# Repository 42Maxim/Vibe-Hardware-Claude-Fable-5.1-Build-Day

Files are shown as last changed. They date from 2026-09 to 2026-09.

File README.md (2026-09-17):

# Vibe Hardware — describe the intent, get the device

<p align="center">
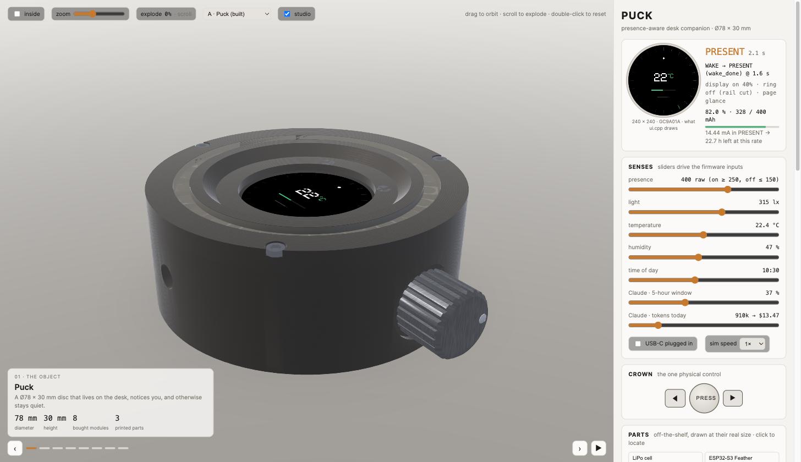
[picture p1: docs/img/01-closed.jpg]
Puck, closed, rendered in the in-browser viewer
  
</p>

**The method has a name, and the first thing it made has a name.** The method is **vibe hardware**.
The object is **Puck**.

## The pitch

Vibe coding gave us "describe the app, get the app." Vibe hardware is the same move on physical things:
**describe what the object should *do*, and get the object** — surveyed, specified, priced, modelled,
firmware'd, and *running on your screen* before a single part is ordered.

You don't hand the model a spec. You hand it an intent: *"something that lives on my desk, notices me, tells me
one thing worth knowing, and otherwise stays quiet."* The model decides the rest — **what** it should be,
**how** it should work, and crucially **what it is made from** — then builds it and lets you hold it,
virtually, from every angle.

## The loop

**Intent → survey → concepts → BOM → geometry → firmware → live emulation.**

The model reads real supplier pages and datasheets *first*, because dimensions are the actual constraints — a
52.3 mm inner diameter decides a form far better than taste does. It proposes several forms, argues each from a
specific part dimension, and commits to one. It locks a shopping list with live links and tonight's prices. It
writes one parametric source of truth that emits both the printable STL **and** the mesh you see. It writes the
firmware. Then it ports that firmware into the browser and *runs it*.

> **`dist/companion.html` is not a 3D model of the device. It is the device.**
> The state machine in that page is the firmware's state machine. The display is drawn pixel-for-pixel by the
> ported `ui.cpp`. The battery drains at the current the datasheets say the real parts draw. Open it with the
> wifi off and it runs: one file, no libraries, no CDN, no assets.

## The hard constraint that makes it real

**Off-the-shelf modules and 3D-printed parts only.** No custom PCB, no tooling, no six-week lead time. Every
component is something a moderately experienced maker can hand-solder, and every plastic part comes off a
desktop printer. That single rule is what turns a beautiful simulation into a thing you can actually own: the
BOM is orderable tonight, the STL is printable tonight, and the gap between the preview and the object on your
desk is a weekend, not a product cycle.

## What it achieves

It collapses the most expensive part of hardware: **the distance between an idea and knowing whether it works.**
Normally you find out the battery can't last a day, or the LED ring doesn't clear the display, after you have
spent the money and two weeks. Here you find out in the browser — the fit check runs exact solid-geometry
booleans, the power table comes from datasheet currents, and the pin budget flags the I²C address collision
before it becomes a returned part.

And it refuses to bluff. The whole project ran under one rule: **nothing is allowed to be merely plausible.**
Every dimension, price, current draw and library version comes from a supplier page or a datasheet that was
actually opened, or it is explicitly marked `unverified`. A made-up number that looks right is worse than a hole.
So the simulation is not a mood board — when it says *22.7 hours left*, that number has a paper trail.

## Puck, the proof

Ø78 × 30 mm. Eight bought modules, three printed parts, ≈ AU$171 / US$95. A presence-aware desk object that
notices when you sit down, shows one thing worth knowing at a glance, glows quietly, and otherwise stays out of
the way: presence, light, temperature and humidity, one knurled crown, a round display, a ring of ambient light,
no tether. 141 detailed sub-parts you can explode with a scroll wheel, down to the bond wires inside the LEDs.
Designed, built and emulated in a single ~2-hour session, from a blank repo.

**Describe the intent. Get a device you can order, print, flash — and play with first.**

| | |
|---|---|
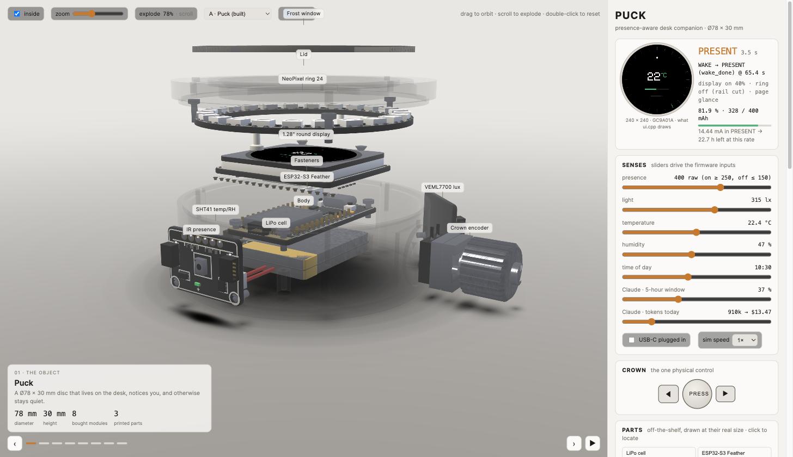
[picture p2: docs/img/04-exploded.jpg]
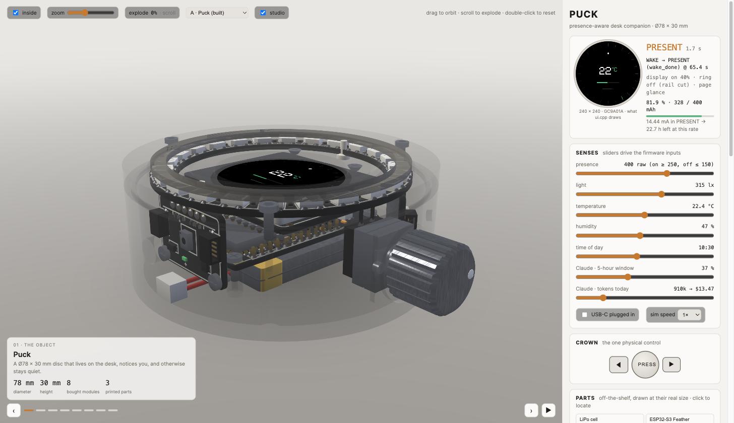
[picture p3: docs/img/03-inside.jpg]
|  |  |
| **Scroll to explode.** Every part leaves along its own assembly axis, fasteners last, labelled as it goes. | **See inside.** The shell goes translucent and the real modules sit where they really sit. |
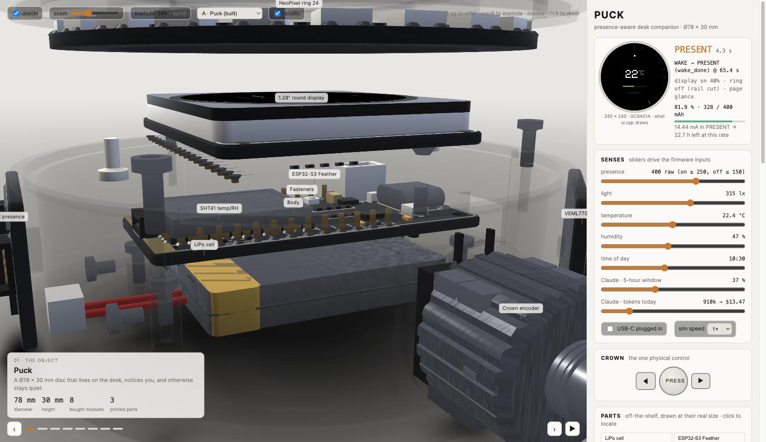
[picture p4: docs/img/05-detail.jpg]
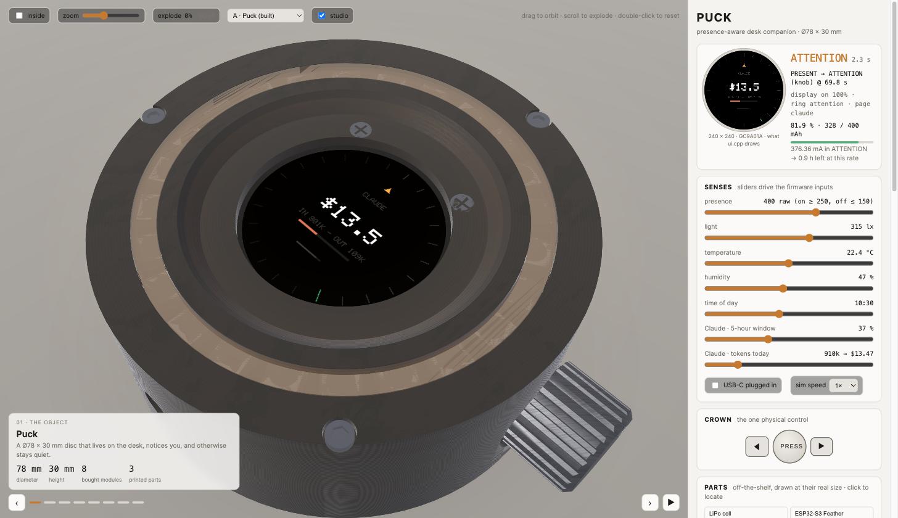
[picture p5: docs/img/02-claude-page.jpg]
|  |  |
| **Real parts, not blocks.** Silkscreen, ENIG pads, solder fillets, castellations, gold headers, Phillips recesses. | **Live display + ambient ring.** Turn the crown to the Claude page; the ring lights, and the power budget reacts. |

---

## What is actually simulated

Most hardware "demos" are an animation of an idea. This one computes:

| Simulated | How |
|---|---|
| **State machine** | `firmware/state_machine.cpp` hand-ported line-for-line to `demo/src/state_machine.js` — same states (`SLEEP · WAKE · PRESENT · NIGHT · ATTENTION · AWAY_PENDING`), same transitions, same guards. The port boundary is marked in a comment banner in both files. |
| **Timing constants** | `build.py` parses every `#define` in `firmware/config.h` and emits them into the page as `FW.*`. Change `T_AWAY_MS` in the firmware and the browser's timeout changes with it. 90 constants cross that boundary. |
| **The display** | `ui.cpp` ported to JS, drawing through a tiny `Adafruit_GFX` shim (including the real 5×7 glcd font) into a 240×240 canvas — the panel's true resolution — which is then textured onto the glass in 3D. `Math.fround` is used where the C code narrows to `float`, so the browser and the MCU round identically. |
| **The LED ring** | `leds.cpp` ported; per-LED colour, brightness cap and animation phase, rendered as 24 emissive segments plus an additive halo through the frosted annulus. |
| **Power** | Per-part, per-mode currents from datasheets in `parts/parts.json` → totals per state → runtime on the chosen cell → the battery readout in the page, drained in real time as you change states. |
| **Fit** | Exact CSG booleans in `geometry/device.py` (not bounding boxes): every component against the internal volume with a 0.5 mm clearance rule. Failures turn red in the 3D view. |
| **Pins** | Every GPIO assigned from `parts.json`, with I²C address collisions flagged (the STHS34PF80 at `0x5A` collides with the DRV2605L haptic — which is why the no-limit tier costs a second board). |

Measured on the page as shipped:

| Mode | Current | Runtime on 400 mAh |
|---|---|---|
| `SLEEP` | 0.12 mA | ~141 days |
| `NIGHT` | 5.04 mA | ~79 h |
| `PRESENT` | 14.44 mA | ~27.7 h |
| `WAKE` / `ATTENTION` (ring lit) | 376.4 mA | ~1 h — event-only by design |

<p align="center">
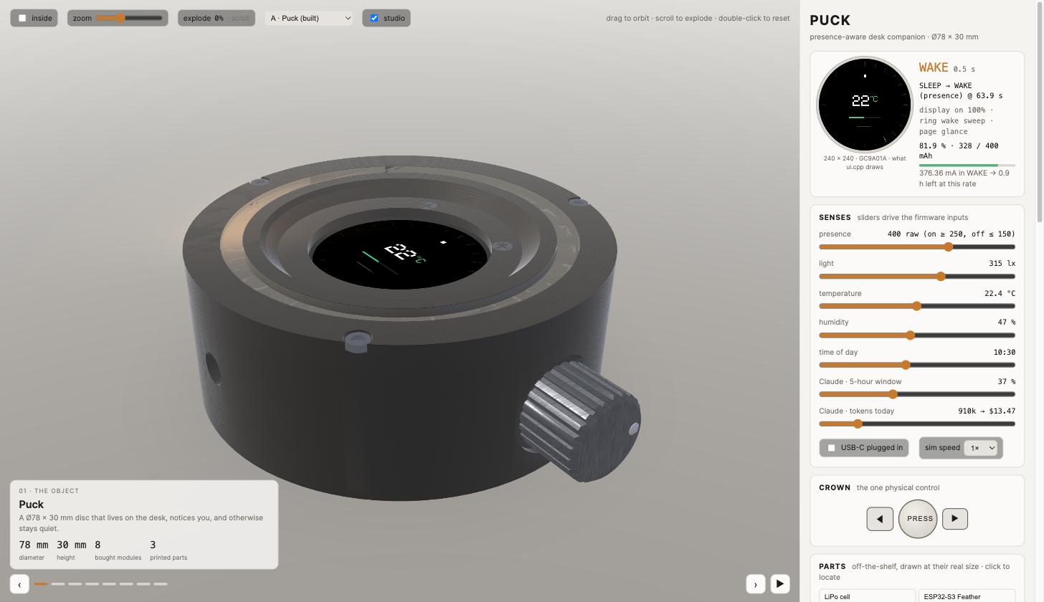
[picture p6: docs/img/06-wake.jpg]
WAKE state: the ring sweeps, the panel reads 376.36 mA and 0.9 h left
  <br>
  <sub><b>SLEEP → WAKE (presence)</b> — the ring sweeps and the readout immediately drops to <b>376.36 mA → 0.9 h left</b>.
  Move the presence slider and the firmware's own transition fires; the cost of that animation is not decorative.</sub>
</p>

The page's own verdict: every continuous mode clears an 8-hour working day; the two ring-lit modes are *burst only*,
which is exactly how the firmware uses them. The ring is the entire power story — 312 mA of the 376 — which is why it
lives on the Feather's **switchable** STEMMA QT rail, is capped at 20 % brightness, and is cut completely in sleep.

---

## How it was designed (the order matters)

1. **Survey the parts first** → [`docs/01-survey.md`](docs/01-survey.md). Real supplier pages and datasheets: board
   footprints, LED ring diameters, battery thicknesses, sensor FoV cones, encoder shaft depths. Dimensions are the
   design constraints, so they come before any drawing.
2. **Four concepts, then commit** → [`docs/02-concepts.md`](docs/02-concepts.md) + a to-scale
   [preview canvas](docs/02-concepts-canvas.html). **A · Puck** ("a hockey puck that knows you're there"),
   **B · Tile** (the lean one), **C · Dial** (the knob *is* the object), **D · Wedge**. Each is argued from a specific
   part dimension, not from taste. Puck won on one number: *the 24-LED ring's 52.3 mm inner diameter is the only ring
   that clears the display module* — the 16-ring's 31.7 mm ID doesn't even clear the 32.5 mm active area. That single
   dimension fixes the cavity, the wall and the whole form. All four still render in the demo's concept switcher.
3. **Lock the BOM** → [`docs/03-bom.md`](docs/03-bom.md). Three tiers, priced in AUD / USD / cheapest-global, every
   line with a live link and one sentence on why that part beat the obvious alternative. Balanced ≈ **AU$171 / US$95**
   (parts 1–8 verified at AU$157.17 / US$88.44); lean ≈ US$50; no-limit ≈ US$130.
4. **One parametric source of truth** → [`geometry/device.py`](geometry/device.py). Python + `manifold3d`. The same
   script emits the printable `build/enclosure*.stl` **and** `build/geometry.json` for the demo, so the thing on
   screen cannot drift from the thing you'd print. It also runs the fit check and prints the verdict.
5. **Firmware** → [`firmware/`](firmware/). Arduino / ESP32-S3, commented, with library versions verified against
   `releases/latest` ([`LIBRARIES.md`](firmware/LIBRARIES.md)) and a host-side test for the state machine.
6. **The demo** → [`demo/src/`](demo/src/) → `python3 build.py` → `dist/companion.html`.

---

## The parts

All off-the-shelf breakouts a moderately experienced maker can hand-solder. No custom PCB, no long leads.

| Module | Why this one |
|---|---|
| Adafruit **ESP32-S3 Feather** (ADA5477) | The only surveyed board with charger + fuel gauge + a *switchable* QT rail — that switch is what cuts the ring's dark current in sleep |
| Adafruit **1.28" round GC9A01A** (ADA6178) | Round glass with two real M2 mounting holes 22.8 mm apart |
| **NeoPixel Ring 24** (ADA1586) | Ø52.3 mm ID — the one ring that clears the display module |
| **STHS34PF80** IR presence (ADA6426) | Lens-free, 80° cone, 10 µA, wakes the MCU on its INT pin |
| **SHT41** (ADA5776) · **VEML7700** (ADA4162) | ±0.2 °C / ±1.8 %RH; 0.0042 lx resolution so a dark room still reads |
| **Bourns PEC11R-4220F-S0024** | 20 mm D-shaft — its 7 mm thread is what lets the crown pass a 3 mm wall with washer and nut |
| 400 / 500 mAh LiPo | The bay is cut 40 × 30 × 6.5 to take either, because the 500 mAh is retired in AU |

---

## Run it

```bash
open dist/companion.html          # that's it — offline, no dependencies
```

Drag to orbit · **scroll to explode** · zoom slider · *inside* toggle · move any sense slider · turn or press the crown.
The panel on the right shows the live state, the last transition that fired, and the battery draining at the modelled rate.

Rebuild everything from source:

```bash
pip install manifold3d numpy
python3 geometry/device.py     # → build/enclosure*.stl + build/geometry.json, prints the fit table
python3 build.py               # → dist/companion.html (inlines geometry, firmware constants, JS/CSS)

# firmware logic test (host-side, no hardware needed)
c++ -std=c++17 firmware/test_state_machine.cpp firmware/state_machine.cpp -o /tmp/sm && /tmp/sm
```

---

## Repo map

| What | Where |
|---|---|
| Parts survey, with a source for every number | `docs/01-survey.md` |
| Concepts A–D + to-scale preview canvas | `docs/02-concepts.md`, `docs/02-concepts-canvas.html` |
| BOM, three tiers × AU/US/global | `docs/03-bom.md`, data in `parts/parts.json` |
| Aesthetic, mechanical, wiring, assembly, quick start | `docs/04-design.md` |
| Parametric geometry → STL + demo mesh + fit check | `geometry/device.py` → `build/` |
| Firmware + host-side test + verified library versions | `firmware/` |
| 1:1 JS port of state machine / display / LEDs | `demo/src/{state_machine,ui,leds}.js`, `demo/src/PORT_CHECK.md` |
| Hand-written WebGL viewer, tables, app | `demo/src/{gl,tables,app}.js` |
| Claude usage push (the device's 5th page) | `tools/claude_usage_push.py` |

### About the viewer

`demo/src/gl.js` is hand-written WebGL1 — shaders, matrix maths, arcball, picking, glow sprites and all. No three.js,
nothing doing the hard part. It renders 144 parts / 82k triangles at ~0.4 ms of CPU per frame, with GGX material
shading driven by a per-part material name (soldermask, ENIG gold, tinned solder, anodised aluminium, glass, pouch
foil, printed PETG…), crease-angle normal smoothing, procedural micro-detail and contact occlusion.

The 141 detailed sub-part meshes come out of the same parametric source as the STL: the WS2812B packages carry their
three dies and bond wires, the boards carry silkscreen and pads as real relief, the screws have Phillips recesses, and
the encoder's D-flat is 4.5 mm across because that is what the Bourns drawing says.

---

<sub>Built on Build Day, Brisbane, 2026-09-16, with Claude Code. Standing rules for the repo live in `CLAUDE.md`;
the original brief is in `PROMPT.md`.</sub>

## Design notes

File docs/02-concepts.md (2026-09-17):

# 02 · Concepts

Four forms, each arranged from the parts in `01-survey.md` at their real dimensions.
Preview: `docs/02-concepts-canvas.html` (to-scale SVG sections, local file, open in a browser).

---

## A · Puck — "a hockey puck that knows you're there"

**Form.** Ø74 × 24 mm disc, flat top, 1 mm radius edge. Frosted ring inset in the top face, round display dead centre, an IR window on the front chamfer, and a knurled crown on the right side like a watch.

**Inside.** Top layer: Adafruit 1.28" round GC9A01 module (42.4 × 36.2 × 5.4) centred, NeoPixel Ring 24 (OD 65.5 / ID 52.3 / 3.2 thick) concentric around it under a 3 mm frosted PETG ring. Middle layer: ESP32-S3 Feather (52.3 × 22.7 × 7.2) running front-to-back with USB-C through the rear wall; SHT41 and VEML7700 lying flat in the left and right crescents beside it (VEML7700 reads ambient through the frosted ring). STHS34PF80 standing vertical against the front wall, element facing forward through a Ø6 window, its 80° cone covers a seated person at 0.5–1.5 m. Bottom layer: 500 mAh cell (36 × 29 × 4.75) under the Feather. PEC11R encoder (20 mm shaft, 7 mm thread) through the right wall.

**The dimension that makes it work.** The 24-ring's 52.3 mm inner diameter clears the display module's 42.4 × 36.2 outline with 5 mm to spare; the 16-ring's 31.7 mm ID does not even clear the 32.5 mm active area. That single number makes this a 24-LED object, fixes the inner cavity at Ø68, and the wall at 3 mm gives Ø74. The Feather's 52.3 mm length sits on a Ø68 chord only within ±11 mm of centre, which is why it runs through the middle and the sensors go in the crescents.
**Fights back.** Height: 2 + 4.75 + 7.2 + 5.4 + 3 with 0.5 mm gaps is 23.4 mm; nothing can be added vertically. The 24-ring idles at ~24 mA dark, so it needs its own high-side switch.

**Easy:** one focal point, symmetric, printable as two parts (body + lid). **Costs:** the 24-ring is the dearest LED option, the crown needs a good knob. **Tier:** balanced.

---

## B · Tile — "a standing card, the lean one"

**Form.** 32 × 16 × 62 mm standing tile in a shallow base, display landscape at eye level.

**Inside.** Adafruit ESP32-S3 Reverse TFT Feather (22.9 × 50.8, 240×135 display on its back face) standing vertically; the tile is the Feather plus 4.5 mm of wall on each side. 350 mAh cell (36 × 19.6 × 5.2) behind it. STHS34PF80 in the base facing forward. SHT41 in the base. No ring: the only ambient light is the Feather's single on-board NeoPixel glowing through the base — or a 12-ring (36.8 OD) laid flat in a Ø40 base as a floor glow.

**The dimension that makes it work.** The Feather's 22.9 mm width is the whole object's width; nothing else needs to fit beside it. **Fights back.** The 1.14" display is off-centre on the Feather (three buttons take the top 8 mm of the face), so the tile's window is asymmetric, and the 240×135 panel at 16 mm wide reads as a status bar, not a face. The three onboard buttons are the "one control" — tactile, not rotary.

**Easy:** cheapest, no display wiring, one board. **Costs:** the ambient light is an afterthought, the display is small. **Tier:** lean.

---

## C · Dial — "the knob is the object"

**Form.** 80 × 56 × 28 mm wedge, 12° top slope. A Ø30 knob rises 8 mm from the top right, a 16-LED ring glows in the annulus around it, a 1.3" square display sits to the left.

**Inside.** NeoPixel Ring 16 (44.5 OD / 31.7 ID / 6.7 thick) under a frosted annulus, PEC11R at its centre with a Ø28 knob (the 31.7 ID leaves 1.85 mm around a 28 mm knob). Adafruit 1.3" 240×240 ST7789 (35.8 × 35.8) at the left. Feather flat under both, 1200 mAh cell (62 × 34) flat under the Feather. STHS34PF80 on the front face.

**The dimension that makes it work.** The 16-ring's 31.7 mm ID is exactly a knob-sized hole; that ring only makes sense around a control. **Fights back.** The ring's 6.7 mm thickness plus the 12.5 mm encoder body under the knob stacks to 19 mm before the Feather, so the wedge is 28 mm tall and the two focal points (knob halo + display) compete.

**Easy:** great tactile feel, long battery (1200 mAh). **Costs:** two visual centres, largest footprint. **Tier:** no-limit (knob machined, ring + display + haptics).

---

## D · Wedge — "a tiny monitor with a halo on the desk"

**Form.** 76 × 50 × 32 mm, 25° sloped face, landscape display.

**Inside.** Adafruit 1.69" 280×240 (45.8 × 36.8) in the sloped face. NeoPixel Ring 12 (36.8 OD) mounted face-down in the base so the glow lands on the desk as an underglow halo. 1200 mAh cell lying flat under the slope. STHS34PF80 above the display. Encoder on the right end.

**The dimension that makes it work.** The 1.69" panel's 38 × 30 mm active area is the largest surveyed that fits a 50 mm-deep face at 25°. **Fights back.** The underglow depends on the desk finish (nothing on black), and the 62 mm cell forces the 76 mm length.

**Easy:** most legible display. **Costs:** the ambient light is indirect and surface-dependent; the form is a familiar "gadget" shape. **Tier:** balanced.

---

## Recommendation: A · Puck

The puck is the only form where every part sits where its dimension wants it: the 24-ring is concentric with the round display because 52.3 > 42.4, the Feather runs through the middle because 52.3 mm fits a Ø68 chord only there, the cell stacks under it because the disc has exactly one layer to spare, and the presence sensor's 80° cone faces the person through the front wall without a lens. One focal point, quiet when you are not there, a crown you can turn without looking. The tile (B) is cheaper but its light and display are compromises; the dial (C) has two centres; the wedge (D) is a shape you have already seen and its glow depends on the desk.

Committed: Puck. Concept previews in `02-concepts-canvas.html`.

**Post-fit note (geometry/device.py):** the concept sketch said Ø74 × 24. The exact fit check grew it to **Ø78 × 30**: the 24-ring cannot share a plane with the display module (the module's corners sit at r 27.9, inside the ring's 26.15 inner radius), so the ring moved up into the lid and the display sits in a 2.4 mm dish below it (+6 mm height); and the VEML7700 standing at 45° needs a Ø72 cavity to clear both the wall and the display corner by 0.5 mm (+4 mm diameter). The sketch's reasoning stands; the numbers in `build/geometry.json` are the truth.

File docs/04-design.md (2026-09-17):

# 04 · Design — Puck

Concept A, locked. Every dimension below comes from `parts/parts.json`, `docs/01-survey.md`,
`docs/03-bom.md` or the locked mechanical layout. Anything I could not derive from those is
written **unverified** rather than filled in. Coordinates: origin at the centre of the base
underside, z up, **−y front** (user), **+y rear** (USB), **+x right** (crown).

Geometry is the post-fit-check layout (cavity Ø72, outer Ø78). Two open items are marked **C1**
and **C2** in §2.4 — each names the problem and the minimum change that clears it.

---

## 1 · Aesthetic direction

A matte black disc the size of a coaster that sits still and says one thing. The top is two
surfaces: a flat rim and a shallow dish sunk 3 mm into it, with the round glass dead centre and
a frosted band of white light around the outside edge — a halo that is either off or holding one
steady colour. The only thing that moves is the crown on the right: a 16 mm knurled cylinder at
finger height, one click per detent, the kind of control you turn without looking down. Material
feel is matte PETG against frost against glass; no gloss, no chrome, no logo, no seam you can see
from a seated eye line. Personality: it notices you and then leaves you alone. It must never blink,
never breathe, never idle-animate, never show a menu, never ask for anything. If you are not
there, it is black and silent, and that is the state it should be in most of the day.

---

## 2 · Mechanical design

### 2.1 Overall

| Dimension | Value | Source |
|---|---|---|
| Outer diameter | Ø78 | layout |
| Cavity diameter | Ø72 (r 36) | layout |
| Total height (feet excluded) | 30 | layout |
| Wall thickness | 3 | layout |
| Floor thickness | 2 (cavity z 2…25) | layout |
| Lid | z 25…30; lip drops into a 1.4 wide × 1.5 deep rebate in the wall top, 0.3 clearance | layout |
| Lid fixing | 3 × M2 at **75° / 195° / 315°** from +x, CCW from above, bolt circle r 36.5; bosses Ø5 with Ø1.6 pilots; lid has M2 clearance holes with 1.5 deep head recesses | layout |
| Lid top rim | annulus r 25.5…39 at z 30 (outer radius follows the new Ø78 — derived) | derived |
| Lid centre dish | r < 22.5, surface at z 27, 45° transition to the rim, 2 thick | layout |
| Display window | Ø34 through the dish | layout |
| Ring pocket | cut from below, z 24…28.4, r 25.45…33.45 | layout |
| Frosted window | annulus r 28.5…32.5, z 28.4…30 | layout |
| IR window (presence) | Ø6 in the front wall at z 14.8 | layout |
| Light window (lux) | Ø3 through the wall at 45° (right-rear), z 14.8 | layout |
| Breathing holes | 4 × Ø2 through the floor under the SHT41, at ±4 from its centre | layout |
| Crown bushing hole | Ø7.2 at y +4, z 12; Ø18 × 1.5 knob dimple outside → 3.1 panel | layout |
| USB-C slot | 12 × 7 through the rear wall, centred z 12 — sized for the plug overmould (overmould size unverified) | layout |
| Feet | 3 × Ø8 silicone bumpers; **foot radius unverified** — keep them clear of the breathing holes | layout |

### 2.2 z-stack on the centreline

| z (mm) | What | Thickness |
|---|---|---|
| 0…2 | floor | 2 |
| 2…8 | LiPo cell (AU 400 mAh, 6 thick; US 500 mAh is 4.75 → 2…6.75) | 6 |
| 8…9 | air over the cell | 1.0 |
| 9…16.2 | ESP32-S3 Feather on 4 posts | 7.2 |
| 16.2…19.2 | wiring plenum | 3.0 |
| 19.2…24.6 | display module (glass top 2.4 below the dish surface at z 27) | 5.4 |
| 24.6…25.0 | gap to the dish underside — 0.4 standoff bosses | 0.4 |
| 25.0…30.0 | lid: ring 25.2…28.4, frost 28.4…30.0, pocket void 24…28.4 at r 25.45…33.45 | 5.0 |

Sum = 30.0. Ring top and frost underside now meet at 28.4 — the earlier 0.3 mm interference between
them is gone, and the LEDs bear straight on the diffuser, which is what you want optically.

### 2.3 Part-by-part mounting

| Part | Size (mm) | Placed at | How it is held |
|---|---|---|---|
| NeoPixel Ring 24 | OD 65.5 / ID 52.3 / 3.2 | lid pocket, z 25.2…28.4, LEDs up against the frost; 0.7 radial clearance each side (pocket r 25.45…33.45 vs ring r 26.15…32.75), 1.2 of pocket below the ring for leads and solder | 3 hot-glue dabs or 2 × M2 nylon screws into lid bosses (fixing method chosen, not in the layout) |
| Frosted window | r 28.5…32.5, 1.6 thick | lid top, z 28.4…30 | printed separately in natural PETG, bonded into the rebate |
| Display module | 42.4 × 36.2 × 5.4 | centred (0, 0), z 19.2…24.6 | 2 × M2 countersunk through the dish into the module's 2 holes, 22.8 apart, onto 0.4 standoff bosses; **hole positions on the PCB unverified** (parts.json) |
| Feather | 52.3 × 22.7 × 7.2 | centre (0, +1.5), long axis front-to-back (y −24.65…+27.65), PCB bottom z 9.0 | 4 posts Ø4 × 7 (M2 self-tap, Ø1.6 pilot — pilot chosen) at (±8.8, −22.1) and (±8.8, +25.1); pattern 17.6 × 47.2, consistent with a 2.5 edge inset, but the Feather's **hole inset is unverified** in the survey |
| LiPo cell | 38 × 25 × 6 (AU) / 36 × 29 × 4.75 (US) | floor, under the Feather, x ±12.5, y −17.5…+20.5, z 2…8 | 40 × 30 × 6.5 bay per BOM line 7, foam pad + one cable tie |
| STHS34PF80 | 25.5 × 17.6 × 4.7 | vertical on the front wall, y −31.5…−26.8, x ±12.75, z 6…23.6, element facing −y | 2 × M2 into ribs off the front wall; the wall is 4.5 off the board back at the centreline, so the ribs carry it |
| VEML7700 | 25.5 × 17.6 × 4.6 (parts.json, **PCB size unverified**) | **vertical** against the wall at 45° (right-rear): inner face r 28.5, outer r 33.1, 25.5 tangential, z 6…23.6, sensor facing out through the Ø3 window at z 14.8 | 2 × M2 into ribs off a flat pad at 45°; 2.9 of air behind the board at its centre |
| SHT41 | 25.5 × 17.6 × 4.8 | **flat on the floor**, left crescent, centred (−22, −2), 25.5 along y, z 2…6.8 | 2 × M2 posts off the floor, over the 4 breathing holes |
| Encoder PEC11R-4220F-S0024 | body 12.5 × 13.4 × 10.7, M7 × 0.75 bushing, 20 mm shaft, 7 mm thread | flat printed pad on the inside of the right wall, mounting face x 34.4; body x 23.7…34.4, y −2.25…+10.25, z 5.3…18.7 | M7 washer + nut outside in the dimple; panel 3.1 thick leaves 3.9 of thread proud |
| Knob | Ø16 × 12, seated in the Ø18 × 1.5 dimple | on the D-flat | grub screw; **part not selected — unverified** (printed or machined) |

### 2.4 Clearances (computed from the layout)

Cavity wall is r 36, so what matters is a part's worst **corner radius**, not its width.

| Pair | Clearance | Note |
|---|---|---|
| Display corners (r 27.88) ↔ cavity wall r 36 | 8.13 | corners at (±21.2, ±18.1) |
| Display active Ø32.5 ↔ window Ø34 | 0.75 radial | glass 38.1 × 35.6 overlapped by 2.05 (x) / 0.80 (y) of bezel |
| Display glass top 24.6 ↔ dish surface z 27 | 2.4 sunk | the dish shades the glass |
| Display top 24.6 ↔ dish underside 25.0 | 0.4 | standoff bosses; the 2 screws pull the module up to them |
| Display top 24.6 ↔ ring underside 25.2 | 0.6 | the module's half-diagonal 27.88 exceeds the ring's 26.15 ID radius, so display and ring are **not** coplanar — 0.6 is all that separates them |
| Display bottom 19.2 ↔ Feather top 16.2 | 3.0 | wiring plenum |
| Feather rear corners (±11.35, +26.65) ↔ wall | 7.51 | wall at y 34.16 for x ±11.35 |
| Feather front corners ↔ wall | 8.51 | |
| Feather PCB bottom 9.0 ↔ cell top 8.0 | 1.0 | 2.25 on the thinner US cell |
| Cell ↔ front / rear posts | 2.6 each | y −17.5 vs post face −20.1; y +20.5 vs +23.1 |
| Cell edge x −12.5 ↔ SHT41 edge x −13.2 | 0.7 | closest pair on the floor |
| Feather rear edge 27.65 ↔ inner wall face 36.0 | 8.35 | USB-C plug reach — the plug overmould enters through the 12 × 7 slot, **see C1** |
| STHS34PF80 back (y −31.5) ↔ wall at x ±12.75 (y −33.67) | 2.17 | 4.5 at the centreline |
| STHS34PF80 rear face −26.8 ↔ Feather front −25.65 | 1.15 | |
| STHS34PF80 rear face −26.8 ↔ front posts (face −25.1) | 1.70 | |
| STHS34PF80 top 23.6 ↔ lid underside 25.0 / ring 25.2 | 1.40 / 1.60 | its top corners sit at r 29.7…34.0, i.e. under the pocket mouth |
| VEML7700 inner face (r 28.5 at 45°) ↔ nearest display corner | **0.71** | display corner projects to 27.79 on the 45° ray |
| VEML7700 outer corners (r 35.47) ↔ cavity wall r 36 | 0.53 | tightest wall clearance in the device |
| VEML7700 ↔ encoder body | 4.33 tangential | encoder's nearest corner sits at t −17.08 on the 45° frame; board spans ±12.75 |
| VEML7700 outer corner ↔ 75° lid boss (Ø5 at r 36.5) | 3.20 | 195° and 315° bosses clear everything by ≥ 4.4 |
| SHT41 corners (r 34.15 / 32.79) ↔ wall | 1.85 / 3.21 | |
| SHT41 top 6.8 ↔ Feather bottom 9.0 | 2.20 | no plan overlap anyway |
| Encoder body top 18.7 ↔ display bottom 19.2 | **0.50** | tightest vertical pair |
| Encoder body ↔ display in plan | 2.50 lateral | body starts at x 23.7, display ends at 21.2 |
| Encoder body rear x 23.7 ↔ Feather x 11.35 | 12.35 | |
| Encoder body bottom 5.3 ↔ floor top 2.0 | 3.30 | |
| Ring pocket outer r 33.45 ↔ lid boss inner edge r 34.0 | 0.55 | the bosses only just miss the pocket |
| Ring OD r 32.75 ↔ lid outer skin r 39 | 6.25 of lid material | |

**Fit verdict: pass on a 0.5 mm rule.** The three closest pairs are encoder-to-display 0.50 (z),
VEML-to-display-corner 0.71, and SHT41-to-cell 0.70 — which matches the geometry fit check.
Two things still need a decision:

- **C1 — USB-C reach.** The Feather sits 1.5 mm rearward (rear edge 8.35 mm from the inner wall
  face; any further and its rear corner breaks the 0.5 mm rule against the 45° VEML board). The slot is
  12 × 7 through the full 3 mm wall so the plug's overmould passes into the cavity and seats on the port;
  nothing lies in that path (posts at x ±8.8, slot ±6). A USB-C plug shell is nominally 6.5 mm long and overmoulds are
  **unverified** (I did not open a connector spec), so **test-fit your actual cable in a printed
  coupon before committing the body print**; if it still does not seat, fit a short USB-C extension pigtail inside.
- **C2 — encoder shaft length.** With the body face at x 34.4, the 7 mm thread ends at x 41.4 —
  3.9 proud of the dimple floor (37.5) for washer and nut, which is right. But the 20 mm shaft ends
  at x 54.4, about 3.9 mm past the outer face of a 12 mm knob, so **cut the shaft to 16 mm** and
  deburr. The knob also needs a counterbore over the nut: depth ≈ 4, diameter **unverified**
  (M7 × 0.75 nut across-flats not read from a datasheet).

### 2.5 Tolerances, print orientation, settings

| Item | Value |
|---|---|
| Pockets (ring, frost rebate, sensor bays, cell bay) | +0.2 on each dimension |
| Lid rebate | 1.4 × 1.5 with +0.3 clearance on the lip (as specified) |
| Bushing hole | Ø7.2 for an M7 × 0.75 bushing |
| M2 self-tap pilots | Ø1.6 (posts and lid bosses) |
| M2 clearance holes | Ø2.4, 1.5 deep head recesses in the lid |
| Body print | floor down, no supports; the USB slot, the Ø6 and Ø3 windows bridge; the Ø7.2 bushing hole prints horizontal and is reamed |
| Lid print | rim face down on the plate, dish and pockets up; no supports |
| Frost print | flat, natural/clear PETG, **0.4 mm layers** (the layer lines are the diffuser) |
| Layers / nozzle | 0.2 mm / 0.4 mm for body and lid |
| Walls / infill | 3 perimeters, 30 % gyroid (chosen) |
| Material / colour | body matte black or warm grey PETG; **all interior surfaces white PETG** for light bounce; frost natural PETG |
| PETG profile | 240 °C / 80 °C bed, 40 mm/s outer wall (chosen defaults) |

### 2.6 Light path and sensing path

- **Halo.** 24 LEDs on a 29.45 pitch radius fire up into a 1.6 mm frost band at r 28.5…32.5, in
  contact with the diffuser — so the band reads as one continuous ring, not 24 dots. White interior
  walls pick up the spill through the open pocket mouth and keep the dish evenly lit from below.
- **Display.** Ø34 window over a Ø32.5 active area: 0.75 mm of bezel all round hides the glass edge
  and the FPC corners, and the glass sitting 2.4 mm below the dish surface shades it from overhead
  office lighting.
- **Presence.** The STHS34PF80 looks out through a Ø6 hole at z 14.8 — about 20 mm above a desk, so
  the 80° cone covers a seated torso at 0.5–1.5 m. Cover with 0.3 mm IR-transparent film or leave
  open; do **not** fill it with PETG, which is opaque in the far IR.
- **Light.** The VEML7700 now looks out sideways through a Ø3 window at 45° (right-rear), z 14.8 —
  no longer under the frost, so it no longer reads its own halo. Two consequences: the aperture is
  small and the view is directional, so absolute lux is wrong by a fixed factor and depends on which
  way the puck faces. **Calibration item:** one scale factor measured against a reference meter, and
  a note in the manual that the crown faces right. Leave the window open or fit clear film — frost
  in front of it would put the halo back into the reading.
- **Air.** Four Ø2 holes through the floor under the SHT41 let room air reach the sensor, so
  humidity tracks the room instead of the sealed case. Temperature still carries the Feather's
  self-heating: measure the offset after 30 min in ATTENTION and put it in `TEMP_OFFSET_C` (or, if
  the firmware has no such constant, calibrate against a reference thermometer and record it).
  Keep the silicone feet clear of the four holes.

---

## 3 · Wiring

One I2C bus, one SPI bus, four GPIO for the crown and the presence interrupt. Pin numbers from
`parts/parts.json` (`pins_src`: arduino-esp32 3.3.11
`variants/adafruit_feather_esp32s3/pins_arduino.h`). Wire colours are my choice — pick any, but
keep this table taped to the bench.

| Feather pin (GPIO) | Colour | Goes to | Note |
|---|---|---|---|
| 3V | red | SHT41 VIN, VEML7700 VIN, STHS34PF80 VIN | **always-on** 3.3 V rail |
| GND | black | every module GND, encoder C (common) | star from the Feather's GND pad |
| SDA (3) | blue | STHS34PF80 SDA → QT chain | bus shared by all sensors + fuel gauge |
| SCL (4) | yellow | STHS34PF80 SCL → QT chain | |
| I2C_POWER (7) | orange | NeoPixel Ring 24 VCC (+5V pad) | switched 3.3 V rail, **ring only** |
| SCK (36) | white | display SCK | SPI |
| MOSI (35) | grey | display SI | SPI; display SO / MISO (37) not connected |
| D10 (10) | violet | display TCS | chip select |
| D9 (9) | brown | display D/C | |
| D6 (6) | pink | display RST | |
| D5 (5) | pale blue | display Lite | backlight PWM (LEDC) |
| 3V / GND | red / black | display Vin / GND | module has its own 3.3 V regulator |
| D11 (11) | green | ring DIN | first pixel |
| A0 (18) | green/white | encoder A | input pull-up, RTC-capable |
| A1 (17) | yellow/white | encoder B | input pull-up, RTC-capable |
| A2 (16) | orange/white | encoder switch | other side to GND; ext1 wake source |
| A3 (15) | brown/white | STHS34PF80 INT | ext1 wake source |
| BAT | — | **nothing** | the ring does not run from VBAT |
| GPIO33 / GPIO21 | — | on-board NeoPixel + its power | unused, power held LOW |

The display's microSD pins (SDCS, SO, CD) are left unconnected — eight conductors go to the
display, not ten.

**STEMMA QT chain.** Feather 3V / GND / SDA / SCL by soldered header wires to the STHS34PF80's
header, then QT cables STHS34PF80 → SHT41 → VEML7700. The Feather's own QT socket is **not** used
for sensors.

| Device | Address |
|---|---|
| VEML7700 | 0x10 (fixed) |
| MAX17048 fuel gauge (on board) | 0x36 (0x0B on an older LC709203F revision) |
| SHT41 | 0x44 |
| STHS34PF80 | 0x5A |

No collisions. Two near misses recorded in `parts.json`: the DRV2605L haptic is also 0x5A (not
fitted) and the I2C QT rotary encoder breakout defaults to 0x36 (not fitted — the crown is wired to
GPIO instead).

**Two electrical compromises, flagged.**

1. **The ring runs below its datasheet minimum.** WS2812B VDD range is 3.5–5.3 V
   (datasheet, via `01-survey.md`); the switched QT rail is 3.3 V. It works in practice — colour
   mixing at low duty is what suffers — and brightness is capped at 20 % by `LED_MAX_BRIGHTNESS` in
   `config.h`, which is also what keeps the ring's on-current at the 312 mA in `parts.json`. The
   clean fix is a VBAT high-side load switch (BOM, no-limit tier), which costs a part and a GPIO.
2. **312 mA through the Feather's QT power switch.** The switch's current rating is **unverified**;
   the 20 % cap is what keeps this plausible. Same fix as above. Do not raise the cap without
   moving the ring to its own switch.
3. **The switched rail must never feed the sensors.** It is cut in SLEEP; the STHS34PF80 is the
   wake source and has to stay alive (10 µA). Sensors on 3V, ring on I2C_POWER — that separation is
   the whole power budget.

---

## 4 · Assembly guide

Empty printed enclosure → finished device. Roughly 2 hours, most of it soldering.

1. **Clean the prints.** Ream the Ø7.2 bushing hole, the Ø6 IR window, the Ø3 light window and the
   four Ø2 breathing holes with a drill bit turned by hand. Check the lid lip in its 1.4 × 1.5
   rebate — with 0.3 clearance it should drop in with finger pressure. Deburr the USB slot and
   test-fit your actual USB-C cable (**C1** — do this before you print the final body).
2. **Bond the frost.** Press the frosted annulus into the lid's top rebate, flush with the rim.
   Cyanoacrylate at three points on the outer edge only — glue in the light path frosts unevenly.
3. **Prepare the ring.** Cut three 120 mm leads (26 AWG) for VCC, GND, DIN. Tin the ring's three
   pads on the *back* face and solder the leads flat so they exit at one point. **Risk 1** below.
4. **Fit the ring.** Ring into the lid pocket (z 25.2…28.4), LEDs facing up against the frost, lead
   exit at **135°** — the widest gap between the 75° and 195° bosses, and clear of the crown (0°),
   the lux window (45°) and the display bundle (90°). Retain with two nylon M2 screws or three
   hot-glue dabs. Route the three leads inboard through the 1.2 mm of pocket below the ring.
5. **Fit the display.** Solder eight leads (150 mm) to Vin, GND, SCK, SI, TCS, D/C, RST, Lite.
   Mount the module to the dish underside with 2 × M2 countersunk screws from the top; the glass
   should sit centred in the Ø34 window with an even bezel. **Risk 3** below.
6. **Install the encoder.** Cut the shaft to 16 mm with a razor saw first and deburr (**C2**), or
   the knob will not seat. From inside, body face flat on the printed pad at x 34.4, bushing out
   through Ø7.2; washer then nut outside, in the Ø18 dimple. **Risk 2** below.
7. **Wire the encoder.** A → A0, B → A1, C → GND, switch → A2 and GND. Leave 60 mm of slack.
8. **Fit the sensor boards.** STHS34PF80 vertical on its front-wall ribs, element centred on the Ø6
   window at z 14.8. VEML7700 vertical on its 45° pad, sensor centred on the Ø3 window at z 14.8 —
   check it is looking *out*, not at the ring. SHT41 flat on its floor posts at (−22, −2), sensor
   side up, not covering the four breathing holes. Solder four header wires (3V, GND, SDA, SCL) to
   the STHS34PF80, then chain STHS34PF80 → SHT41 → VEML7700 with 50 mm QT cables; the SHT41 sits
   between them physically as well as electrically, so the short cable goes left first.
9. **Fit the cell.** Foam pad in the bay, cell in, leads dressed to the rear. Do not plug in yet.
10. **Mount the Feather.** Four M2 self-tap screws into the posts, USB-C aligned with the rear slot.
    Check that the port centre lands inside the slot before tightening.
11. **Solder the harness.** Work through the §3 table one row at a time and tick each off. Ring VCC
    to I2C_POWER — not to BAT, not to 3V.
12. **Smoke test with the lid loose.** Plug in USB-C. `I2C scan` should return 0x10, 0x36, 0x44,
    0x5A. Flash the firmware (§5) and confirm the display lights and the halo comes up white at 20 %.
13. **Plug in the cell.** Confirm the fuel gauge reports a sane percentage, then unplug USB and
    confirm the device still runs.
14. **Close up.** Dress all wiring below z 19 so nothing sits between the display top and the dish,
    and nothing crosses the encoder body (only 0.5 mm above it). Lid on, three M2 screws at
    75° / 195° / 315°, snug only — heads sit in the 1.5 mm recesses. Press on the knob into the
    dimple, grub screw on the D-flat. Three silicone feet at 120°, clear of the breathing holes.

**The three steps most likely to go wrong.**

- **Risk 1 — soldering the ring after it is in the pocket.** You cannot: the pads face down into a
  pocket whose mouth is 0.6 mm above the display, and the iron will melt the frost it is pressed
  against. *How to not:* solder all three leads before the ring goes anywhere near the lid, keep
  every joint under 1.2 mm proud of the PCB back (that is the whole pocket depth under the ring —
  tin the pad, tin the wire, one touch), and check the ring lies flat in the pocket on a flat
  surface before you commit glue.
- **Risk 2 — over-torquing the encoder nut on a 3.1 mm printed panel.** PETG creeps; a
  hard-tightened M7 nut will craze the dimple within a week and the crown will wobble. *How to not:*
  a washer under the nut, tighten by hand plus one-eighth turn with pliers, and use a drop of
  removable thread-lock to hold it instead of torque. Support the inside of the wall with a finger
  while you tighten.
- **Risk 3 — the display bundle fouling the lid.** Eight wires leave a module that is screwed to the
  lid, so they twist every time the lid is lifted, and there is only 3.0 mm of plenum, 0.4 mm over
  the module and 0.6 mm between the module's corners and the ring. *How to not:* leave 150 mm and
  dress the bundle as a flat ribbon of two rows of four exiting to the rear at x ≈ 0, tied down at
  z 18; never route it into the ring pocket or outboard of r 25.45, and check nothing is pinched by
  lifting the lid 40 mm before the final screw-down.

---

## 5 · Quick start

### Flash

Arduino IDE 2.x. Boards Manager: **esp32 by Espressif Systems, 3.3.11**. Board:
**Adafruit Feather ESP32-S3 2MB PSRAM** (string verified in that release's `boards.txt`).
Libraries (Library Manager) — every version below was verified today against the upstream
GitHub release:

| Library | Version |
|---|---|
| Adafruit GFX Library | 1.12.6 |
| Adafruit GC9A01A | 1.1.1 |
| Adafruit NeoPixel | 1.15.5 |
| Adafruit SHT4x | 1.0.5 |
| Adafruit VEML7700 | 2.1.6 |
| Adafruit STHS34PF80 | 1.0.2 |
| Adafruit MAX1704X | 1.0.3 |
| Adafruit BusIO | 1.17.4 |

Plug in USB-C, pick the port, upload. If the port does not appear, or the sketch left the chip in
deep sleep: hold **BOOT**, tap **RESET**, release BOOT — that is the ROM bootloader (it is a native
USB serial port, no adapter). Set `LED_MAX_BRIGHTNESS` and the two calibration constants — lux
scale for the Ø3 side window, and `TEMP_OFFSET_C` for self-heating — in `config.h` before the
first real use; if the firmware has no such constants, record both offsets against a reference
meter and apply them by hand.

### Charge

USB-C from any charger. Charging is built into the Feather and starts whenever USB is present; the
board has a **charge LED** next to the USB connector (Adafruit product page 5477). The exact LED
pattern for "full" and for "no battery attached" is **unverified** — the product page names the LED
but does not specify its behaviour. **Charge current is unverified** (not stated on the product
page). On the 400 mAh AU cell, expect a charge measured in low single-digit hours; the on-screen
percentage comes from the MAX17048, not from a timer. The device stays usable while charging.

### Use

Turn it on by sitting down. The STHS34PF80 wakes the Feather on its INT line.

| State | Screen | Halo | Meaning |
|---|---|---|---|
| SLEEP | off | off | nobody there for the idle timeout; ~0.1 mA |
| PRESENT | backlight 40 % | off | you are at the desk, the glance state |
| NIGHT | backlight 10 % | off | present, but the room is dark |
| ATTENTION | backlight 100 % | on | something wants you — the halo colour is the message |
| WAKE | backlight 100 % | on | you touched the crown; full brightness while you interact |

**The crown.** Turn to move between pages, one detent per page, no acceleration, no wrap-around
animation. Press to acknowledge whatever put the device in ATTENTION and drop straight back to
PRESENT. Press and hold to re-centre on page 1.

**The halo.** It is a single steady colour or it is off. Off means nothing needs you. A lit halo
means ATTENTION, and the colour is the whole vocabulary — it never pulses, chases or animates,
because a desk object that blinks is a desk object you turn face-down. Mapping of colour to
condition is firmware policy and lives in `config.h`.

**The three detail pages** (turn the crown from the home face):

1. **Room** — temperature and relative humidity from the SHT41, large numerals, with the trend over
   the last hour as a thin arc. Humidity breathes through the four floor holes; temperature carries
   a self-heating offset — see the §2.6 calibration note.
2. **Light** — lux from the VEML7700 and the day's curve, which is what decides NIGHT. Scaled by the
   calibration factor, because the sensor reads through a Ø3 window facing right-rear, not upward.
3. **Power** — battery percentage and voltage from the MAX17048, plus estimated runtime in the
   current state from the power table.

Home face is the clock and one line of whatever matters. Everything else is a page you have to ask
for, which is the point.

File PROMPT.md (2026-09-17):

# Build Day prompt — Breakthrough track

Paste as one message. Model: claude-fable-5-1, effort high.
Standing rules live in CLAUDE.md and load automatically.

---

Design a small physical device/object that lives on a desk, senses what is happening around
it, and responds — and prove the whole thing on screen, from first principles. You
have about two hours and limited credits; spend them on the object and the demo.

You choose what the object actually is. Below is a direction, not a spec.

The spirit: a Teenage Engineering–grade desk object. Restrained, intentional,
premium. Something I would leave out on a clean desk rather than hide in a drawer. It
should notice me, tell me one thing worth knowing at a glance, and otherwise stay
quiet. My starting sketch is a presence-aware ambient companion — a small display,
ambient light, a few environmental senses, one good physical control, battery, no
tether. The sketch is negotiable. The taste bar is not.

## 1. Survey the parts before you design anything

Browse. Read the actual supplier pages and the datasheets behind them. I am not
naming parts and I don't want a shopping list yet — I want to know what is really
available and what shape it comes in: board footprints, display sizes and aspect
ratios, LED ring diameters, battery thicknesses, sensor field-of-view cones, encoder
shaft depths, connector positions. Those dimensions are the real design constraints,
so get them before you draw anything.

## 2. Show me three or four concepts, then pick one

Each concept gets: a name, one line of character, the form described in words with
rough dimensions, and — this is the part I care about — **how the real parts arrange
inside that form, and which specific part dimension makes the form work or fight
back**. "A disc, because the LED ring is 60 mm and the display sits in its middle
without an offset" is the kind of reasoning I want. "A disc, because discs are
elegant" is not.

For each, tell me what the form makes easy, what it costs, and which BOM tier it
suits. Then recommend one and say plainly why it beats the others.

Do not wait for my approval. Present the concepts, commit to your recommendation,
keep going. I'll interrupt if I disagree — that's what Esc is for. Once committed,
don't revisit it.

## 3. Lock the BOM

Now the real shopping list for the chosen concept. For every part: exact module name,
supplier, a real link, current price, and one line on why that part over the obvious
alternative.

Budget is flexible — no fixed number. Give three tiers: lean, the balanced one you
recommend, and one where cost stops mattering. Total each, one line of trade-off
each. Then tell me which two or three parts are worth the money and which are a waste.

Off-the-shelf breakouts a moderately experienced maker can hand-solder. No custom PCB,
nothing on a long lead time.

## 4. One parametric source of truth for the geometry

Pick your own approach, including installing a CAD or mesh package if that is the
fastest route to a correct model. Whatever you choose, the enclosure geometry is defined once,
parametrically, and that same definition produces both the STL I would print and the
mesh the demo renders. A model drawn by hand for the demo that merely resembles the
case is precisely the thing I do not want. Component bodies placed at the dimensions
you read in step 1.

## 5. The demo: one self-contained HTML file

No external libraries, no CDN, no assets. It must open on a laptop with the wifi off
and work.

- Real-time 3D of the device, rotatable, rendered with WebGL you write yourself. No
  three.js. No library doing the hard part.
- Geometry inlined from the parametric source above.
- A toggle to see inside: shell goes translucent, the real components sit where they
  really sit.
- The device runs live: the display rendered at its true pixel resolution showing
  exactly what the firmware would draw, and the ambient lighting rendered as it would
  actually glow.
- Sliders for every sensed quantity — presence, light level, temperature, humidity,
  time of day — and the physical controls as clickable elements.
- Current state and the last transition that fired, shown live.
- Battery readout driven by the power budget below, not a number you picked.

## 6. The state machine in the browser is the firmware's state machine

Same states, same transitions, same timer constants, ported directly — not a second
implementation that behaves similarly. If I change a timeout in the firmware it should
be obvious which line in the page changes with it. Mark the port boundary in a comment.

## 7. Three computations that must actually compute

Each one a table, each ending in a verdict.

1. **Pin budget** — every pin assigned, every peripheral accounted for, conflicts and
   I2C address collisions flagged explicitly.
2. **Fit** — bounding box of every component against the internal volume, with
   clearances. Pass or fail. Visible in the 3D inside-view.
3. **Power** — per-part current draw per mode from the datasheets, totals, predicted
   runtime per mode on the chosen cell. If a mode cannot last a working day, say so and
   tell me what to change.

## 8. Also produce

Aesthetic direction (a short paragraph on look, material feel, personality). Mechanical
design: dimensions, internal layout, mounting, clearances. Wiring as a structured
pin-to-module list. Assembly guide, numbered, empty enclosure to finished device, with
the two or three steps most likely to go wrong called out. Complete commented firmware
with libraries named and versions verified. Quick start: flash, charge, use.

## Order of work

Ship in the order above. If the clock runs out, the tail is what is missing. Two items
are explicitly droppable — do them last, and drop them without asking me:

- An exploded assembly animation on a scrub bar.
- A concepts panel in the demo showing the forms you rejected in step 2.

## Done means

The HTML file opens with wifi off and runs with no console errors. The 3D renders and
rotates. Moving any slider visibly changes the display and the lighting. All three
tables pass. The geometry script runs and writes an STL. The BOM has a real total I
could order from tonight.

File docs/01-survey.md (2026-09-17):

# 01 · Parts survey — what is really available, and what shape it comes in

Every number below was read from the linked supplier page or datasheet on 2026-09-16.
"unverified" = I could not open a source that states it; treat as a hole, not a fact.
Prices are the supplier's list price in USD on the day (AU/US/global pricing is in the BOM).

## MCU boards (all ESP32-S3, all have USB-C, LiPo charger, deep sleep)

| Board | Footprint (mm) | Sleep current | Notable | Price | Source |
|---|---|---|---|---|---|
| Adafruit ESP32-S3 Feather 4MB/2MB PSRAM (#5477) | 52.3 × 22.7 × 7.2, 6.3 g | ~100 µA deep sleep (from LiPo) | STEMMA QT with switchable power, MAX17048 fuel gauge, JST-PH LiPo 0.425" from left edge, USB-C centre-left | $17.50 | [adafruit.com/product/5477](https://www.adafruit.com/product/5477), [Feather spec 0.9" × 2.0"](https://learn.adafruit.com/adafruit-feather/feather-specification) |
| Adafruit ESP32-S3 Reverse TFT Feather (#5691) | Feather outline 0.9" × 2.0" = 22.9 × 50.8 (height unverified) | 40–50 µA deep sleep | 1.14" 240×135 ST7789 IPS on the back face, 3 tactile buttons, STEMMA QT, MAX17048 | $24.95 | [adafruit.com/product/5691](https://www.adafruit.com/product/5691) |
| Seeed XIAO ESP32-S3 | 21 × 17.8 | 14 µA deep sleep | Charge 50 mA fast / 3.8 mA trickle, 11 GPIO, battery pads on the underside (position unverified), no fuel gauge, no QT connector | $7.49 | [seeedstudio.com](https://www.seeedstudio.com/XIAO-ESP32S3-p-5627.html), [wiki](https://wiki.seeedstudio.com/xiao_esp32s3_getting_started/) |

ESP32-S3 chip currents (Espressif datasheet v2.2, Table 5-9 / 5-10, 3.3 V, 25 °C):
modem-sleep 80 MHz WAITI 22.0 mA · 80 MHz dual core 32-bit 33.1 mA · 240 MHz WAITI 32.9 mA · 240 MHz dual core 66.2 mA · light-sleep 240 µA · deep-sleep RTC mem 8 µA · Wi-Fi TX peak 283–340 mA · Wi-Fi RX 88 mA · BLE RX 93 mA.
Source: [esp32-s3_datasheet_en.pdf](https://documentation.espressif.com/esp32-s3_datasheet_en.pdf) pp. 66–68.

## Displays

| Display | Module (mm) | Active area | Res / driver | Power | Price | Source |
|---|---|---|---|---|---|---|
| Adafruit 1.28" round TFT + microSD (#6178) | 42.4 × 36.2 × 5.4, glass 38.1 × 35.6, 2 holes 22.8 apart | Ø32.5 (1.28" diag) | 240×240 GC9A01A, 220 ppi, IPS | backlight unverified (Waveshare twin below: 31.2 mA whole module) | $17.50 | [adafruit.com/product/6178](https://www.adafruit.com/product/6178) |
| Waveshare 1.28" LCD Module (GC9A01) | 40.4 × 37.5, round body Ø37.5 | Ø32.4, 0.135 mm pixel | 240×240 GC9A01, IPS, SPI | 31.2 mA @ 3.3 V (module, backlight on) | see BOM | [waveshare wiki](https://www.waveshare.com/wiki/1.28inch_LCD_Module) |
| Adafruit 1.3" square TFT + microSD (#4313) | 35.8 × 35.8 × 5.3, 4 holes 33 × 30 | 26 × 26 | 240×240 ST7789, 260 ppi, IPS | backlight unverified | $16.95 | [adafruit.com/product/4313](https://www.adafruit.com/product/4313) |
| Adafruit 1.69" round-rect TFT (#5206) | 45.8 × 36.8 × 5.4 | 38 × 30 | 280×240 ST7789, IPS | backlight unverified | $17.50 | [adafruit.com/product/5206](https://www.adafruit.com/product/5206) |
| Adafruit SHARP Memory 1.3" (#3502) | 40 × 39 × 4.6, 4 holes | 24.5 × 21 | 168×144 mono, SPI write-only | 4 µA @ 1 Hz refresh, no backlight | $24.95 | [adafruit.com/product/3502](https://www.adafruit.com/product/3502) |
| Reverse TFT Feather built-in | on the MCU board | 1.14" | 240×135 ST7789 | unverified | incl. | above |

Shape lesson: the round 1.28" panels are the only ones whose *glass* is round; every other panel is a rectangle with a rectangular FPC tail, so a round face needs a bezel that hides corners.

## Ambient LED rings (WS2812B / SK6812 5050, Adafruit NeoPixel)

| Ring | OD / ID (mm) | Thickness | LEDs | Price | Source |
|---|---|---|---|---|---|
| NeoPixel Ring 12 (#1643) | 36.8 / 23.3 | 6.7 | 12 | $8.95 | [adafruit.com/product/1643](https://www.adafruit.com/product/1643) |
| NeoPixel Ring 16 (#1463) | 44.5 / 31.7 | 6.7 | 16 | $9.95 | [adafruit.com/product/1463](https://www.adafruit.com/product/1463) |
| NeoPixel Ring 24 (#1586) | 65.5 / 52.3 | 3.2 | 24 | $16.95 | [adafruit.com/product/1586](https://www.adafruit.com/product/1586) |

LED current: ~18 mA per colour channel constant-current (Adafruit), 60 mA/pixel full white ([Überguide](https://learn.adafruit.com/adafruit-neopixel-uberguide/powering-neopixels)); measured "just under 1 mA per LED when just sitting there dark" ([PJRC measurement](https://www.pjrc.com/how-much-current-do-ws2812-neopixel-leds-really-use/)) — the dark current is the number that matters for battery life, so the ring must be power-switched.
Package 5.0 × 5.0 mm, VDD absolute range 3.5–5.3 V ([WS2812B datasheet](https://cdn-shop.adafruit.com/datasheets/WS2812B.pdf)) — on a 3.7 V cell they run at cell voltage, which works in practice and is marginal on the datasheet.

The ring geometry is the design driver: the 16-ring's 31.7 mm ID is *smaller* than the 1.28" panel's Ø32.5 active area, so the ring cannot sit around the round display in the same plane. The 24-ring's 52.3 mm ID clears the whole 42.4 × 36.2 display module with 5 mm to spare. The 12-ring's 23.3 mm ID fits nothing but a knob.

## Batteries (Adafruit LiPo, 2-pin JST-PH, protected)

| Cell | L × W × T (mm) | Weight | Price | Source |
|---|---|---|---|---|
| 350 mAh (#2750) | 36 × 19.6 × 5.2 | 8.2 g | $6.95 | [adafruit.com/product/2750](https://www.adafruit.com/product/2750) |
| 500 mAh (#1578) | 36 × 29 × 4.75 | 10.5 g | $7.95 | [adafruit.com/product/1578](https://www.adafruit.com/product/1578) |
| 1200 mAh (#258) | 62 × 34 × 5 | 23 g | $9.95 | [adafruit.com/product/258](https://www.adafruit.com/product/258) |
| 2000 mAh (#2011) | 60 × 36 × 7 | 34 g | $12.50 | [adafruit.com/product/2011](https://www.adafruit.com/product/2011) |

All are 5–7 mm thick slabs; the 1200 mAh at 62 mm long is longer than a Feather (50.8 mm).

## Presence sensing

| Sensor | Field of view | Range | Interface / address | Current | Size | Price | Source |
|---|---|---|---|---|---|---|---|
| STHS34PF80 IR presence (Adafruit #6426) | 80° | up to 4 m, no lens needed | I2C **0x5A**, INT pin | 10 µA @ 1 Hz ODR, 1.5 µA power-down | 25.5 × 17.6 × 4.7 | $14.95 | [product](https://www.adafruit.com/product/6426), [pinouts](https://learn.adafruit.com/adafruit-sths34pf80-ir-presence-motion-sensor/pinouts), [SparkFun hookup guide (current)](https://docs.sparkfun.com/SparkFun_Qwiic_Human_Presence_Sensor-STHS34PF80/hardware_overview/) |
| Mini PIR (Adafruit #4871) | 100° | 2–5 m | digital out, 2 s hold | unverified | lens Ø13.8 | $3.95 | [product](https://www.adafruit.com/product/4871) |
| Hi-Link LD2410C 24 GHz mmWave | ±60° | 5 m, 0.75 m resolution | UART + GPIO, **5–12 V supply** | unverified | unverified (vendor: "16 × 22 mm" class) | see BOM | [hlktech](https://www.hlktech.net/index.php?id=1095) |

The STHS34PF80 needs no Fresnel lens and no window cut-out beyond an IR-transparent aperture, which is why it wins for a clean face. The PIR needs a 13.8 mm dome; the mmWave needs 5 V.

## Environment and light

| Sensor | Address | Current | Size | Price | Source |
|---|---|---|---|---|---|
| SHT41 temp/RH (Adafruit #5776) | 0x44 | 80 nA idle, 0.4 µA @ 1 Hz | 25.5 × 17.6 × 4.8 | $5.95 | [product](https://www.adafruit.com/product/5776) |
| AHT20 temp/RH (Adafruit #4566) | 0x38 | unverified | unverified | $4.50 | [product](https://www.adafruit.com/product/4566) |
| VEML7700 lux (Adafruit #4162) | **0x10 fixed** | 2–45 µA operating (PSM), 0.5 µA shutdown; 0–140 klx | PCB unverified (STEMMA QT class) | $4.95 | [product](https://www.adafruit.com/product/4162), [Vishay datasheet](https://www.vishay.com/docs/84286/veml7700.pdf) p.2, p.6 |
| BME280 on Feather variant | 0x77 | — | on-board | — | not surveyed |

## Physical control

| Part | Key dimensions | Interface | Price | Source |
|---|---|---|---|---|
| Bourns PEC11R 12 mm encoder | body 12.5 × 13.4, bushing M7 × 0.75 (7 mm behind panel with switch), shaft L = 15/20/25/30 mm, threaded LB = 5 (15 mm) or 7 mm, D-flat F = 7/10/12 mm; 12/18/24 detents; push switch 0.5 mm travel | quadrature A/B/C + switch | see BOM | [PEC11R datasheet](https://www.bourns.com/docs/product-datasheets/pec11r.pdf) |
| Adafruit I2C QT Rotary Encoder breakout + NeoPixel (#4991) | 25.6 × 25.3 × 4.6, takes PEC11-pinout encoder | I2C 0x36 (–0x3D via jumpers) | $5.95 | [product](https://www.adafruit.com/product/4991) |
| Adafruit ANO nav encoder (#5001) + QT adapter (#5740) | adapter 40.7 × 35.8 × 4.8; knob diameter unverified | I2C seesaw, 16 addresses | $8.95 + $4.95 | [5001](https://www.adafruit.com/product/5001), [5740](https://www.adafruit.com/product/5740) |
| DRV2605L haptic driver (Adafruit #2305) | 25.8 × 17.8 × 4.6 | I2C **0x5A — collides with STHS34PF80** | $7.95 | [product](https://www.adafruit.com/product/2305), [pinouts](https://learn.adafruit.com/adafruit-drv2605-haptic-controller-breakout/pinouts) |

Encoder lesson: with a 15 mm shaft only 5 mm is threaded, so the panel it passes through can be at most ~3.5 mm thick after the washer and nut. A 20 mm shaft has 7 mm of thread and leaves 13 mm for a knob.

## Constraints these dimensions impose (carried into the concepts)

1. A round display + LED ring in one plane forces the 24-pixel ring (65.5 mm OD). The 16-ring only works stacked *under* a smaller display or around the knob.
2. Every board is a STEMMA QT rectangle of about 25.5 × 17.6 mm; four of them plus a Feather need ~1200 mm² of floor, or two stacked layers.
3. Cells are 5 mm slabs; 500 mAh (36 × 29) fits beside a Feather in a 60 mm footprint, 1200 mAh (62 × 34) does not without going under.
4. STHS34PF80 and DRV2605L both sit at 0x5A: pick one, or give the haptic its own bus.
5. Ring dark current ≈ 1 mA/LED means a 24-ring idles at ~24 mA — more than the rest of the device combined. It must be on a switched rail (the Feather's STEMMA QT power switch is 3.3 V only; the ring wants VBAT so it needs its own high-side switch).

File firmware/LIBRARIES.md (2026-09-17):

# Puck firmware — pinned library versions

Every version below is the latest GitHub release as of **2026-09-16**, read from
`GET /repos/{owner}/{repo}/releases/latest` (via `gh api`) and then confirmed by
fetching the actual header at that tag from `raw.githubusercontent.com`. No
version here was recalled from memory.

| Library | Version | Released | Verified how |
|---|---|---|---|
| [Adafruit_GFX](https://github.com/adafruit/Adafruit-GFX-Library) | 1.12.6 | 2026-04-09 | `releases/latest`; fetched `Adafruit_GFX.h`, `Adafruit_GFX.cpp`, `Adafruit_SPITFT.h`, `glcdfont.c` at tag `1.12.6` |
| [Adafruit_GC9A01A](https://github.com/adafruit/Adafruit_GC9A01A) | 1.1.1 | 2023-06-07 | `releases/latest`; fetched `Adafruit_GC9A01A.h/.cpp` at tag `1.1.1` |
| [Adafruit_NeoPixel](https://github.com/adafruit/Adafruit_NeoPixel) | 1.15.5 | 2026-05-12 | `releases/latest`; fetched `Adafruit_NeoPixel.h` at tag `1.15.5` |
| [Adafruit_SHT4X](https://github.com/adafruit/Adafruit_SHT4X) | 1.0.5 | 2024-07-30 | `releases/latest`; fetched `Adafruit_SHT4x.h` at tag `1.0.5` |
| [Adafruit_VEML7700](https://github.com/adafruit/Adafruit_VEML7700) | 2.1.6 | 2024-02-06 | `releases/latest`; fetched `Adafruit_VEML7700.h` at tag `2.1.6` |
| [Adafruit_STHS34PF80](https://github.com/adafruit/Adafruit_STHS34PF80) | 1.0.2 | 2025-11-04 | `releases/latest`; fetched `Adafruit_STHS34PF80.h` at tag `1.0.2` |
| [Adafruit_MAX1704X](https://github.com/adafruit/Adafruit_MAX1704X) | 1.0.3 | 2024-03-25 | `releases/latest`; fetched `Adafruit_MAX1704X.h` at tag `1.0.3` |
| [Adafruit_BusIO](https://github.com/adafruit/Adafruit_BusIO) | 1.17.4 | 2025-09-22 | `releases/latest` (transitive dependency of the sensor libraries) |
| [arduino-esp32](https://github.com/espressif/arduino-esp32) | 3.3.11 | 2026-07-22 | `releases/latest`; fetched `package.json`, `cores/esp32/esp32-hal-ledc.h`, `variants/adafruit_feather_esp32s3/pins_arduino.h`, `idf_component.yml` at tag `3.3.11` |

Board: **Adafruit Feather ESP32-S3 2MB PSRAM** (product ADA5477).

## API calls checked against the headers, not guessed

| Call in this firmware | Where it is declared |
|---|---|
| `Adafruit_SHT4x::begin(TwoWire*)`, `setPrecision(sht4x_precision_t)`, `setHeater(sht4x_heater_t)`, `getEvent(sensors_event_t*, sensors_event_t*)` | `Adafruit_SHT4x.h` @1.0.5 lines 116–125 |
| `SHT4X_MED_PRECISION`, `SHT4X_NO_HEATER` | same header, lines 53–66 |
| `Adafruit_VEML7700::begin(TwoWire*)`, `setGain(uint8_t)`, `setIntegrationTime(uint8_t, bool)`, `enable(bool)`, `readLux(luxMethod)` | `Adafruit_VEML7700.h` @2.1.6 lines 86–114 |
| `VEML7700_GAIN_1`, `VEML7700_IT_100MS`, `VEML_LUX_CORRECTED_NOWAIT` | same header, lines 38–48, 72–76 |
| `Adafruit_STHS34PF80::begin(uint8_t, TwoWire*)`, `setBlockDataUpdate`, `setObjAveraging`, `setOutputDataRate`, `setIntPolarity(bool active_low)`, `setIntOpenDrain`, `setIntLatched`, `setIntMask`, `setIntSignal`, `readPresence()` | `Adafruit_STHS34PF80.h` @1.0.2, class declaration |
| `STHS34PF80_ODR_1_HZ`, `STHS34PF80_AVG_TMOS_128`, `STHS34PF80_PRES_FLAG`, `STHS34PF80_INT_OR` | same header |
| `Adafruit_MAX17048::begin(TwoWire*)`, `cellPercent()`, `chargeRate()` | `Adafruit_MAX1704X.h` @1.0.3 lines 60–71 |
| `Adafruit_GC9A01A(cs, dc, rst)`, `begin(uint32_t freq = 0)`, `setRotation` | `Adafruit_GC9A01A.h` @1.1.1 lines 104–120 |
| `GC9A01A_SLPIN` = 0x10, `GC9A01A_DISPOFF` = 0x28 | same header, lines 36 and 42 |
| `Adafruit_SPITFT::sendCommand(uint8_t, const uint8_t* = NULL, uint8_t = 0)` — **public** | `Adafruit_SPITFT.h` @1.12.6 line 215 (`public:` at line 133, `protected:` not until line 378) |
| Default SPI clock 40 MHz on ESP32 | `Adafruit_GC9A01A.cpp` @1.1.1, `#define SPI_DEFAULT_FREQ 40000000` under `#elif defined(ESP8266) || defined(ESP32)` |
| `Adafruit_NeoPixel(n, pin, NEO_GRB + NEO_KHZ800)`, `begin`, `setPixelColor(n,r,g,b)`, `setBrightness`, `clear`, `show` | `Adafruit_NeoPixel.h` @1.15.5 lines 88, 131, 223–236 |
| `ledcAttach(pin, freq, resolution)`, `ledcWrite(pin, duty)` | `cores/esp32/esp32-hal-ledc.h` @3.3.11 lines 89 and 111 (the 3.x pin-based API; the 2.x `ledcSetup`/`ledcAttachPin` pair no longer exists) |
| `esp_sleep_enable_ext1_wakeup_io(mask, ESP_EXT1_WAKEUP_ANY_LOW)`, `esp_sleep_enable_timer_wakeup(us)` | esp-idf `esp_sleep.h`; arduino-esp32 3.3.11's `idf_component.yml` pins `idf: ">=5.3,<6.2"` |
| `WiFi.mode(WIFI_STA)`, `WiFi.setSleep(bool)` | `libraries/WiFi/src/WiFiGeneric.h` @3.3.11 lines 106 and 112 (`WiFiGenericClass::mode`, `setSleep`) |
| `WiFi.begin(const char* ssid, const char* pass)`, `WiFi.status()`, `WiFi.disconnect(bool)` | `libraries/WiFi/src/WiFiSTA.h` @3.3.11 lines 147, 182, 166 |
| `WIFI_STA`, `WIFI_OFF`, `WL_CONNECTED` | `libraries/WiFi/src/WiFiType.h` @3.3.11 lines 35, 34, 49 |
| `WebServer(int port)`, `begin()`, `handleClient()`, `stop()`, `on(uri, HTTPMethod, fn)`, `arg(const String&)`, `send(int, const char*, const String&)` | `libraries/WebServer/src/WebServer.h` @3.3.11 lines 105, 108, 110, 113, 154, 187, 215 |
| `HTTP_POST` | `libraries/WebServer/src/HTTP_Method.h` @3.3.11: `typedef enum http_method HTTPMethod`, i.e. the http_parser enum |
| A POST body with a non-form content type lands in `arg("plain")` | `libraries/WebServer/src/Parsing.cpp` @3.3.11 lines 227–230 (`arg.key = F("plain")`) |

## JSON on the device: no library

`POST /claude` carries five flat numbers. `companion.ino` pulls them out with
`String::indexOf` + `strtod` (`jsonNum`, ~12 lines) rather than adding a parser.
**ArduinoJson 7.4.3** (released 2026-03-02, read from
`GET /repos/bblanchon/ArduinoJson/releases/latest` via the GitHub API on
2026-09-16) is the upgrade path if the payload ever grows nesting, arrays or
string values — it is *not* a dependency of this firmware today.

The parser was exercised on the host against the real payload
`tools/claude_usage_push.py --dry-run` emits, plus a truncated and a non-JSON
body: the two valid ones parse, the two bad ones are rejected (HTTP 400).

## Wi-Fi is off by default

`CLAUDE_WIFI_ENABLED` is `0`, and everything above is inside `#if
CLAUDE_WIFI_ENABLED`, so by default the radio is never initialised and the
power table is unchanged. See the estimate in `companion.ino`: the ESP32-S3
datasheet's 88 mA Wi-Fi RX figure is a peak, and the modem-sleep average for an
associated idle station is **unverified** here.

## Two facts that shaped the design, both read from source

1. **ESP32-S3 has no per-pin ext1 wake level.** `SOC_PM_SUPPORT_EXT1_WAKEUP_MODE_PER_PIN`
   is not defined in `components/soc/esp32s3/include/soc/soc_caps.h` (only
   `SOC_PM_SUPPORT_EXT1_WAKEUP` is). All ext1 pins therefore share one trigger
   level. `ENC_SW` idles HIGH on its pull-up, so the group cannot be ANY_HIGH.
   The STHS34PF80 INT is configured active-low open-drain instead and the group
   wakes on **ANY_LOW** — see `power.cpp`.
2. **Every GPIO in `config.h` is the variant's own number**, taken from
   `variants/adafruit_feather_esp32s3/pins_arduino.h` at tag 3.3.11:
   `SDA 3, SCL 4, I2C_POWER 7, MOSI 35, SCK 36, MISO 37, PIN_NEOPIXEL 33,
   NEOPIXEL_POWER 21`.

## Not verified

* **`PRESENCE_ON_THRESH` / `PRESENCE_OFF_THRESH`** — I did not open the ST
  STHS34PF80 datasheet, so the raw TPRESENCE counts in `config.h` are bench
  knobs, not datasheet values. Print `sths.readPresence()` with a person at
  0.8 m and set them from what you see.
* **The GC9A01A post-SLPIN delay** in `power.cpp` is a conventional 10 ms; the
  exact minimum is in the panel datasheet, which I did not open.
* **The Wi-Fi power cost when `CLAUDE_WIFI_ENABLED` is 1.** The ESP32-S3
  88 mA Wi-Fi RX figure is quoted second-hand — I did **not** open the ESP32-S3
  datasheet to confirm it. And even taken at face value it is a peak, not the
  average of an associated station in modem sleep, which is what this code
  actually does; that average I neither found nor measured. Both numbers are
  holes, not estimates.
* **Nothing in this directory has been compiled by `arduino-cli`** — no ESP32
  toolchain or library set is installed here. What *has* been compiled and run
  on this machine with `c++ -std=c++17` is the hardware-free part:
  `state_machine.cpp` (against `test_state_machine.cpp`) and `ui.cpp` (against a
  trace-only `Adafruit_GFX` stub). `power.cpp` and `companion.ino` are unbuilt.

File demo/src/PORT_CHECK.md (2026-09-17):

# Port check — firmware ↔ demo

Three JS files are line-for-line ports of three C++ files. This is the map, and
the two checks that prove they still agree.

* `firmware/state_machine.cpp` → `demo/src/state_machine.js`
* `firmware/leds.cpp` → `demo/src/leds.js`
* `firmware/ui.cpp` → `demo/src/ui.js` (part 2; part 1 is the Adafruit_GFX shim)

Rule: **no number that exists in `firmware/config.h` is typed into a JS file.**
The build script turns every `#define NAME value` into `FW.NAME`. Change a
timing in `config.h` and both sides move together.

---

## 1. Functions

### state_machine

| C++ (`firmware/state_machine.cpp`) | line | JS (`demo/src/state_machine.js`) | line |
|---|---|---|---|
| `enum State` (in `state_machine.h`) | h:17 | `const SLEEP … AWAY_PENDING` | 11–16 |
| `enum RingMode` | h:27 | `const RING_OFF … RING_LOW_BATT` | 19–22 |
| `enum Page` | h:35 | `const PAGE_GLANCE … PAGE_CLAUDE` | 25–29 |
| `#define PAGE_COUNT 5` | h:42 | `const PAGE_COUNT = 5` | 32 |
| `sm_state_name` | 12 | `sm_state_name` | 38 |
| `sm_go` | 23 | `sm_go` | 49 |
| `sm_night` | 34 | `sm_night` | 60 |
| `sm_init` | 45 | `sm_init` | 71 |
| `sm_step` | 59 | `sm_step` | 82 |

`struct Inputs` / `Outputs` / `Transition` / `SM` (state_machine.h 44–78) are
plain JS objects with the same field names; only `reason` differs in type
(`const char*` vs string).

### leds

| C++ (`firmware/leds.cpp`) | line | JS (`demo/src/leds.js`) | line |
|---|---|---|---|
| `led_scale` | 12 | `led_scale` | 11 |
| `leds_compute` | 19 | `leds_compute` | 18 |

One deliberate difference, marked in the JS: the C signature takes
`float brightnessCap`, so the cap is narrowed to single precision before the
double maths. `leds.js` calls `Math.fround(brightnessCap)` to reproduce that.
Without it a handful of channels round one step low — the LED trace diff below
catches exactly that.

### ui

| C++ (`firmware/ui.cpp`) | line | JS (`demo/src/ui.js`) | line |
|---|---|---|---|
| — (Adafruit_GFX itself) | — | `GLCDFONT` (1280 bytes, machine copy of glcdfont.c @1.12.6) | 21 |
| — (Adafruit_GFX itself) | — | `class GFX` shim | 88 |
| `ui_fmt0` | 20 | `ui_fmt0` | 325 |
| `ui_fmt1` | 26 | `ui_fmt1` | 331 |
| `ui_fmt_tok` | 32 | `ui_fmt_tok` | 337 |
| `ui_strlen` | 43 | `ui_strlen` | 348 |
| `ui_accent` | 51 | `ui_accent` | 354 |
| `ui_print_centred` | 61 | `ui_print_centred` | 364 |
| `ui_print_at` | 70 | `ui_print_at` | 373 |
| `ui_hour_ring` | 80 | `ui_hour_ring` | 383 |
| `ui_state_glyph` | 101 | `ui_state_glyph` | 404 |
| `ui_rh_bar` | 121 | `ui_rh_bar` | 424 |
| `ui_batt_pip` | 134 | `ui_batt_pip` | 437 |
| `ui_claude_bar` | 154 | `ui_claude_bar` | 457 |
| `ui_degree` | 172 | `ui_degree` | 475 |
| `ui_page_glance` | 179 | `ui_page_glance` | 482 |
| `ui_page_temp` | 196 | `ui_page_temp` | 498 |
| `ui_page_rh` | 205 | `ui_page_rh` | 506 |
| `ui_page_batt` | 215 | `ui_page_batt` | 515 |
| `ui_page_claude` | 229 | `ui_page_claude` | 528 |
| `ui_draw` | 261 | `ui_draw` | 552 |

Two rounding rules keep the two identical and are followed everywhere:

* numbers are formatted with integer maths (`floor(v + 0.5)`, then `/10` and
  `%10`), never `%f` or `toFixed`, so C++ and JS round the same way;
* every coordinate is `floor(x + 0.5)` on a `double`, which
  `Math.floor(x + 0.5)` matches bit for bit.

One deliberate difference, the same one `leds.js` has: `ui_fmt0` / `ui_fmt1` in
the JS call `Math.fround(v)` first. Every field they format (`tempC`, `rh`,
`vbatPct`, `claudeUsd`) is a `float` in the C `UiModel`, so the C++ side rounds
a value already narrowed to single precision. The trace diff below found this:
`claudeUsd = 103.45` printed `$103.5` in JS and `$103.4` in C++ until the
`fround` went in.

`ui_page_claude`'s token line is ASCII (`IN 812K - OUT 96K`), not a middot. A
UTF-8 `·` is two bytes to C++'s `print()` and one code unit to JS's, so the two
ports would draw different glyphs from the same source character.

## 2. Constants

Every one of these is read from `FW.<NAME>` in the JS and from the `#define` in
`firmware/config.h` in the C++. The build-script regex is
`#define ([A-Z0-9_]+) +([-0-9.]+)`; 90 names currently match.

| Used by | `config.h` names |
|---|---|
| `sm_step` timing | `T_WAKE_MS`, `T_AWAY_MS`, `T_ATTENTION_MS`, `RING_LOWBATT_MS`, `TICK_MS` |
| `sm_night` | `LUX_NIGHT`, `LUX_HYST` |
| `sm_step` backlight | `BL_PRESENT`, `BL_NIGHT`, `BL_ATTENTION` |
| `sm_step` ring | `VBAT_LOW_PCT` |
| `leds_compute` | `LED_COUNT`, `LED_MAX_BRIGHTNESS`, `LED_SWEEP_MS`, `LED_SWEEP_FADE_MS`, `LED_TAIL`, `LED_BREATH_MS`, `LED_BREATH_FLOOR`, `LED_PULSE_MS`, `LED_PULSE_COUNT`, `LED_WARM_R/G/B`, `LED_AMBER_R/G/B`, `LED_RED_R/G/B` |
| `ui_accent`, `ui_rh_bar` | `TEMP_COMFORT_LO/HI`, `RH_COMFORT_LO/HI` |
| `ui_hour_ring` | `LUX_DAY`, `UI_TICK_R_OUT`, `UI_TICK_R_IN`, `UI_TICK_R_IN_NOW`, `SCREEN_CX`, `SCREEN_CY` |
| `ui_*` layout | `UI_BIG_Y`, `UI_LABEL_Y`, `UI_BAR_Y`, `UI_BAR_W`, `UI_BAR_H`, `UI_PIP_Y`, `UI_PIP_W`, `UI_GLYPH_Y` |
| `ui_page_claude`, `ui_claude_bar` | `CLAUDE_STALE_MIN`, `COL_CLAUDE` |
| colours (RGB565 as decimal so the regex sees them) | `COL_BG`, `COL_INK`, `COL_DIM`, `COL_FAINT`, `COL_GREEN`, `COL_AMBER`, `COL_RED`, `COL_CLAUDE` |
| firmware only (no JS use) | all `PIN_*`, `I2C_ADDR_*`, `BL_PWM_*`, `PRESENCE_ON/OFF_THRESH`, `SENSOR_PERIOD_MS`, `ENC_*`, `CLOCK_*`, `T_SLEEP_POLL_S`, `SCREEN_W/H/R`, `CLAUDE_WIFI_ENABLED`, `CLAUDE_HTTP_PORT` |

`build.py` prints a WARNING naming every firmware-only constant; the two
`CLAUDE_*` ones on that list are expected, like the `PIN_*` group.

Wi-Fi credentials are strings, so they cannot live in `config.h` (the regex
takes numbers only, and a password has no business in the published HTML).
They are in `firmware/secrets.h`, from `firmware/secrets.h.example`.

`PAGE_COUNT` is the one constant the JS declares itself — it lives in
`state_machine.h`, not `config.h`.

## 3. The checks

### C++ side

```
c++ -std=c++17 -Wall -Wextra -o /tmp/puck_sm \
    firmware/test_state_machine.cpp firmware/state_machine.cpp && /tmp/puck_sm
```

### JS side — same scenario, same expected log

Run from the repo root:

```
node -e '
const fs=require("fs"),vm=require("vm"),R=process.cwd();
const FW={};for(const l of fs.readFileSync(R+"/firmware/config.h","utf8").split("\n")){const m=l.match(/#define ([A-Z0-9_]+) +([-0-9.]+)/);if(m)FW[m[1]]=parseFloat(m[2]);}
const c=vm.createContext({FW,console,Math,String,Number,Object,Array,Uint8Array,Uint8ClampedArray});
for(const f of["state_machine.js","leds.js","ui.js"])vm.runInContext(fs.readFileSync(R+"/demo/src/"+f,"utf8"),c,{filename:f});
vm.runInContext("globalThis.api={sm_init,sm_step,sm_state_name,leds_compute,ui_draw,GFX,RING_WAKE_SWEEP,RING_ATTENTION,RING_LOW_BATT,PAGE_GLANCE,PAGE_DETAIL_TEMP}",c);
const A=c.api;
console.log("FW constants parsed from config.h:",Object.keys(FW).length);
function scen(t,i){i.presence=t>=50000?false:t>=47000?true:t>=16000?false:t>=15000?true:t>=12000?false:t>=100;
i.lux=t>=46500?1:t>=2500?200:t>=2000?2:200;i.vbatPct=t>=46500?10:80;
i.encDelta=t===3000?1:0;i.encPressed=t===49000;i.tempC=22.4;i.rh=46;i.hour=14.5;i.charging=false;i.nowMs=t;}
const EXP=[[100,"SLEEP","WAKE","presence"],[1600,"WAKE","PRESENT","wake_done"],[2000,"PRESENT","NIGHT","lux_low"],[2500,"NIGHT","PRESENT","lux_high"],[3000,"PRESENT","ATTENTION","knob"],[11000,"ATTENTION","PRESENT","attention_idle"],[12000,"PRESENT","AWAY_PENDING","presence_lost"],[15000,"AWAY_PENDING","PRESENT","presence_back"],[16000,"PRESENT","AWAY_PENDING","presence_lost"],[46000,"AWAY_PENDING","SLEEP","away_timeout"],[47000,"SLEEP","WAKE","presence"],[48500,"WAKE","NIGHT","wake_done_dark"],[49000,"NIGHT","ATTENTION","knob"],[50000,"ATTENTION","AWAY_PENDING","presence_lost"],[80000,"AWAY_PENDING","SLEEP","away_timeout"]];
const sm={},i={},o={};A.sm_init(sm);let n=0,f=0;
for(let t=0;t<=80100;t+=FW.TICK_MS){const b=sm.state;scen(t,i);A.sm_step(sm,i,o);
if(sm.state!==b){const L=sm.lastTransition,r=[L.atMs,A.sm_state_name(L.from),A.sm_state_name(L.to),L.reason];
console.log("  "+String(r[0]).padStart(6)+" ms  "+r[1].padEnd(12)+" -> "+r[2].padEnd(12)+"  ("+r[3]+")");
const e=EXP[n];if(!e||e.join()!==r.join()){console.log("    !! expected "+(e?e.join(" "):"<none>"));f++;}n++;}
if(t===3100&&(o.page!==A.PAGE_DETAIL_TEMP||o.ringMode!==A.RING_ATTENTION))f++;
if(t===47100&&o.ringMode!==A.RING_LOW_BATT)f++;
if(t===49100&&o.page!==A.PAGE_GLANCE)f++;
if(t===46100&&(o.displayOn||o.backlight!==0))f++;}
if(n!==EXP.length)f++;
console.log("\n"+n+" transitions, "+f+" failures");
if(f)process.exit(1);console.log("PASS");'
```

The C++ side prints one extra line first, from `page_cycle_test()` — a check
the JS scenario has no counterpart for, because it only ever turns the knob
once:

```
  page cycle: 5 pages, one lap returns to GLANCE, -1 wraps to PAGE_CLAUDE
```

Then both print the same 15 lines:

```
   100 ms  SLEEP        -> WAKE          (presence)
  1600 ms  WAKE         -> PRESENT       (wake_done)
  2000 ms  PRESENT      -> NIGHT         (lux_low)
  2500 ms  NIGHT        -> PRESENT       (lux_high)
  3000 ms  PRESENT      -> ATTENTION     (knob)
 11000 ms  ATTENTION    -> PRESENT       (attention_idle)
 12000 ms  PRESENT      -> AWAY_PENDING  (presence_lost)
 15000 ms  AWAY_PENDING -> PRESENT       (presence_back)
 16000 ms  PRESENT      -> AWAY_PENDING  (presence_lost)
 46000 ms  AWAY_PENDING -> SLEEP         (away_timeout)
 47000 ms  SLEEP        -> WAKE          (presence)
 48500 ms  WAKE         -> NIGHT         (wake_done_dark)
 49000 ms  NIGHT        -> ATTENTION     (knob)
 50000 ms  ATTENTION    -> AWAY_PENDING  (presence_lost)
 80000 ms  AWAY_PENDING -> SLEEP         (away_timeout)

15 transitions, 0 failures
PASS
```

### Trace diffs (stronger than the transition log)

Two extra checks were run outside the repo (they need a throwaway trace-only
`Adafruit_GFX` stub, which does not belong in `firmware/`):

* **`ui_draw`** — the C++ and JS versions were each given nine models (the five
  pages, one "everything else" model at 28.7 °C / 18 %RH / hour 6 / 9 % battery
  / charging / ATTENTION / 900 lux, and three more that walk PAGE_CLAUDE's
  branches: fresh + known window, never-received + unknown window, age exactly
  `CLAUDE_STALE_MIN`, and one stale) and made to log every primitive call.
  **371 calls, byte-identical** (after the `Math.fround` fix above).
* **`leds_compute`** — all four ring modes × t = 0…3000 ms in 50 ms steps ×
  24 pixels. **244 frames, byte-identical** (after the `Math.fround` fix).

## Known limits

* The ports agree on the *primitive calls*, and `ui.js`'s GFX shim is a
  faithful port of Adafruit_GFX 1.12.6's rasterisers, but nobody has diffed the
  browser's pixels against a photo of the real panel.
* `ui_fmt0` / `ui_fmt1` round half **up** and assume non-negative values. A
  sub-zero temperature would print wrong on both sides, identically.
* `PAGE_CLAUDE`'s numbers come from an HTTP push, and `claudeAgeMin` is measured
  against the same drifting RTC-memory second counter as the hour ring — the
  stale threshold is therefore approximate by the same amount the clock is.

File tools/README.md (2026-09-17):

# tools/claude_usage_push.py

Reads local Claude Code transcripts (`~/.claude/projects/**/*.jsonl`), sums
today's (local date) token usage per assistant message, prices it, and POSTs
a small JSON payload to a Puck device at `http://<host>:<port>/claude`.
Stdlib only, no dependencies.

Deduplicates by assistant message id (transcripts can repeat entries).

## Usage

```bash
# Preview today's usage without sending anything
python3 tools/claude_usage_push.py --dry-run --once

# Run the built-in price/logic check (no network, no transcript reads)
python3 tools/claude_usage_push.py --selftest

# Push once to a specific host
python3 tools/claude_usage_push.py --host 192.168.1.50 --port 8080 --once

# Loop forever, posting every 30s (host defaults to $PUCK_HOST or puck.local)
python3 tools/claude_usage_push.py --interval 30
```

Payload shape: `{"usd": <float>, "in": <int>, "out": <int>, "window_pct": <int>, "ts": <unix seconds>}`.
`in` is `input_tokens + cache_creation_input_tokens + cache_read_input_tokens` summed; `out` is `output_tokens`.

## Price table (USD per 1M tokens: input / output)

| Model prefix | Input | Output |
|---|---|---|
| claude-fable-5-1, claude-fable-5 | 10 | 50 |
| claude-opus-5, claude-opus-4-8, claude-opus-4-7, claude-opus-4-6 | 5 | 25 |
| claude-sonnet-5 | 2 | 10 |
| claude-sonnet-4-6 | 3 | 15 |
| claude-haiku-4-5 | 1 | 5 |
| unknown model | 5 | 25 (+ warning on stderr) |

Cache read = 10% of the model's input rate. Cache write (cache creation) = 125% of the input rate.
Matching is by longest-prefix against the model id in the transcript (which carries a date suffix, e.g. `claude-opus-5-20260115`).

**These rates are what the user supplied for this task, not fetched from a pricing page — unverified.**
Check them against Anthropic's current pricing before relying on them for real billing decisions.

`window_pct` (5-hour rate-limit window utilization) **cannot be computed from local transcripts** —
there is no field in the JSONL that reports it. The script always sends `-1` unless you pass
`--window-pct N` yourself.

## Alternative for org-wide numbers (not implemented here)

For **organization-wide** usage (not just this machine's local sessions), Anthropic exposes
the **Usage & Cost Admin API**: `GET /v1/organizations/usage_report/messages`. It requires an
Admin API key (`sk-ant-admin...`) and is plain HTTP (no SDK helper for this endpoint as of
this writing). It reports usage across the whole organization, not one developer's local
Claude Code sessions — a materially different number than what this script sums.

The exact query parameters and response shape were **not verified here** (no admin key was
available to test against the live endpoint). Don't assume the shape without checking
Anthropic's Admin API docs first.

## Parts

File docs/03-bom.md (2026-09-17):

# 03 · BOM — Puck

Prices read on 2026-09-16 from the linked pages. AU = AUD inc GST, US = USD, Global = USD from the cheapest genuine listing I could open (AliExpress/Amazon pages could not be opened from here; those lines are marked **unverified** and priced from the listing title only).
Electrical data for every part lives in `parts/parts.json` — the page's pin and power tables are computed from that file.

## Balanced (recommended) — what I'd order tonight

| # | Part | Why this over the obvious alternative | AU | US | Global |
|---|---|---|---|---|---|
| 1 | **Adafruit ESP32-S3 Feather 4MB/2MB PSRAM** (ADA5477) | Only board surveyed with LiPo charger + fuel gauge + *switchable* STEMMA QT rail in one; the switch is what lets the ring and sensors be cut in sleep. XIAO is cheaper but has no gauge, no QT rail switch and needs its own charger wiring. | [$32.60 Core](https://core-electronics.com.au/adafruit-esp32-s3-feather-with-4mb-flash-2mb-psram-stemma-qt-qwiic.html) | [$17.50](https://www.adafruit.com/product/5477) | same |
| 2 | **Adafruit 1.28" round 240×240 GC9A01A + EYESPI** (ADA6178) | Round glass, 2 mounting holes 22.8 mm apart, 3.3 V regulator on board. Waveshare twin is cheaper but its round body (Ø37.5) has no mounting holes. | [$32.55 Core](https://core-electronics.com.au/adafruit-1-28-inch-round-tft-lcd-display-microsd-eyespi-gc9a01a.html) | [$17.50](https://www.adafruit.com/product/6178) | [Waveshare 1.28" LCD Module](https://www.waveshare.com/1.28inch-lcd-module.htm) — €15.90 at [welectron](https://www.welectron.com/Waveshare-19192-128inch-LCD-Module_1), waveshare.com price **unverified** |
| 3 | **NeoPixel Ring 24** (ADA1586) | The only ring whose 52.3 mm ID clears the display module. Genuine Adafruit = known LED type and 3.2 mm thickness; clones vary in thickness and LED (SK6812 vs WS2812B), which changes the lid recess. | [$33.90 Core](https://core-electronics.com.au/neopixel-ring-24-x-ws2812-5050-rgb-led-with-integrated-drivers.html) | [$16.95](https://www.adafruit.com/product/1586) | [AliExpress 24-LED WS2812B ring ~US$1.96](https://www.aliexpress.com/item/32808302785.html) **unverified** (thickness not stated) |
| 4 | **Adafruit STHS34PF80 IR presence** (ADA6426) | Lens-free, 80° cone, 10 µA, has an INT pin to wake the MCU. PIR needs a 13.8 mm dome and holds for only 2 s; mmWave needs 5 V. Core only lists the SparkFun version (out of stock), so AU is Little Bird. | [$29.05 Little Bird](https://littlebirdelectronics.com.au/products/adafruit-sths34pf80-ir-presence-motion-sensor-ada6426) | [$14.95](https://www.adafruit.com/product/6426) | same (no known clone) |
| 5 | **Adafruit SHT41** (ADA5776) | ±0.2 °C / ±1.8 %RH, 0.4 µA. AHT20 is $1.45 cheaper and ±0.3 °C / ±2 %RH — not worth the accuracy loss on a device whose one job is telling you the room. | [$10.50 Core](https://core-electronics.com.au/adafruit-sensirion-sht41-temperature-humidity-sensor-stemma-qt-qwiic.html) | [$5.95](https://www.adafruit.com/product/5776) | same |
| 6 | **Adafruit VEML7700** (ADA4162) | 0–140 klx with 0.0042 lx resolution, so it reads a dark room without saturating in sun; BH1750 tops out at 65 klx and has no power-save modes. | [$9.10 Core](https://core-electronics.com.au/adafruit-veml7700-lux-sensor-i2c-light-sensor.html) | [$4.95](https://www.adafruit.com/product/4162) | same |
| 7 | **Cell**: AU → Core CE04375 400 mAh 38 × 25 × 6 mm; US → Adafruit 500 mAh 36 × 29 × 4.75 mm (ADA1578) | The 500 mAh is retired at Core and out of stock at Little Bird, so the cell bay is cut 40 × 30 × 6.5 to take either. 1200 mAh does not fit the disc without a third layer. | [$5.55 Core](https://core-electronics.com.au/polymer-lithium-ion-battery-400mah-38456.html) | [$7.95](https://www.adafruit.com/product/1578) | same |
| 8 | **Bourns PEC11R-4220F-S0024** (20 mm D-shaft, switch, 24 detents) | Adafruit #377 is the same family but its shaft length is unstated; the crown needs the 20 mm shaft's 7 mm thread to pass a 3 mm wall with washer and nut. | [$3.92 DigiKey AU](https://www.digikey.com.au/en/products/detail/bourns-inc/PEC11R-4220F-S0024/4499660) | [$2.69 DigiKey](https://www.digikey.com/en/products/detail/bourns-inc/PEC11R-4220F-S0024/4499660) | same |
| 9 | STEMMA QT cables 50 mm × 3 (ADA4399) | Sensors chain without soldering. | ~$1.90 ea Core **unverified** | $0.95 ea **unverified** | same |
| 10 | M2 × 6 screws × 6, M2 heat-set inserts × 6, 22 AWG silicone wire | Hardware; any supplier. | ~$8 | ~$6 | ~$3 |
| | **Total** | | **≈ AU$171** (1–8 verified: $157.17; 9–10 estimated) | **≈ US$95** (1–8: $88.44) | **≈ US$70** (XIAO/Waveshare/AliExpress substitutions, mostly unverified) |

## Lean

Swap 1 → **Seeed XIAO ESP32-S3** ([$7.49](https://www.seeedstudio.com/XIAO-ESP32S3-p-5627.html); no fuel gauge, ring rail needs an external switch), 2 → Waveshare 1.28" (€15.90), 3 → AliExpress ring (unverified), 4 → **Mini PIR** ([$3.95](https://www.adafruit.com/product/4871), needs a Ø14 dome in the lid, 2 s hold), 5 → AHT20 ([$4.50](https://www.adafruit.com/product/4566)), 6 → keep VEML7700, 8 → Adafruit #377 ([$4.50](https://www.adafruit.com/product/377), knob included).
**Total ≈ US$50.** Trade-off: no battery gauge on screen, a PIR dome breaks the flat lid, and the XIAO's 11 GPIO leave zero spare pins.

## No-limit

Balanced plus: Feather → same (nothing better exists in this footprint with a gauge); ring → **NeoPixel Ring 24 RGBW natural white** ([ADA2862, Core](https://core-electronics.com.au/neopixel-ring-24-x-5050-rgbw-leds-w-integrated-drivers-natural-white-4500k.html), price unverified) for a true white halo; crown → machined aluminium knob (Adafruit #5093-class, unverified); add **DRV2605L haptic** ([$7.95](https://www.adafruit.com/product/2305)) + LRA — **but it shares 0x5A with the STHS34PF80**, so it only works if the presence sensor moves to the SparkFun mini board's SPI mode ([Core, out of stock](https://core-electronics.com.au/sparkfun-mini-human-presence-and-motion-sensor-sths34pf80-qwiic.html)); add a proper high-side load switch for the ring instead of the QT rail. Frosted ring in cast resin instead of printed PETG.
**Total ≈ US$130 / AU$230.** Trade-off: the haptic forces a second presence board and SPI wiring; the RGBW ring changes the LED library call.

## Worth the money / waste

- **Worth it:** the STHS34PF80 (a flat lid with no dome is the whole look), the Feather (fuel gauge + switched rail are what make the power table pass), the Bourns encoder with a known shaft length (the crown geometry depends on it).
- **Waste:** the microSD slots on the Adafruit display (never used, adds 5 mm to the module), the RGBW ring (you see it for 1.5 s), haptics (address collision for a buzz).

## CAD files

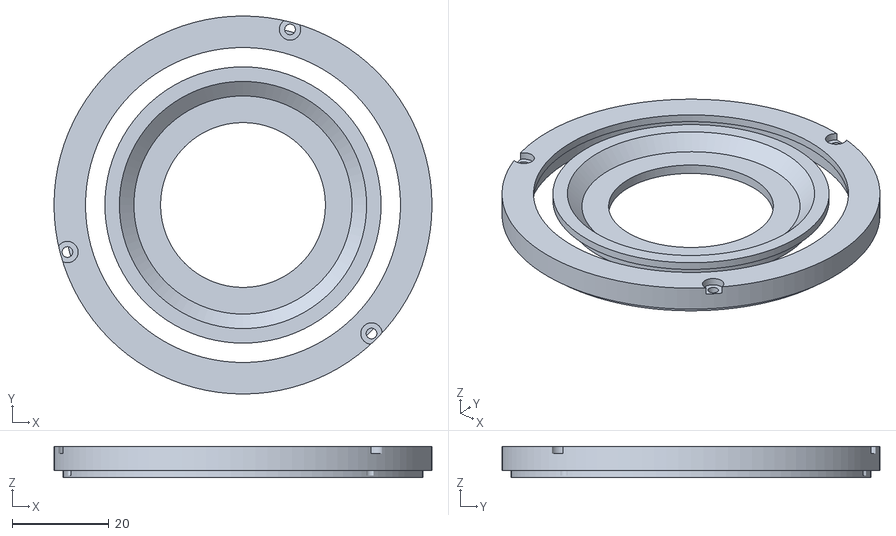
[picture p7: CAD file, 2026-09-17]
build/enclosure_lid.stl
78.0 x 78.0 x 6.50

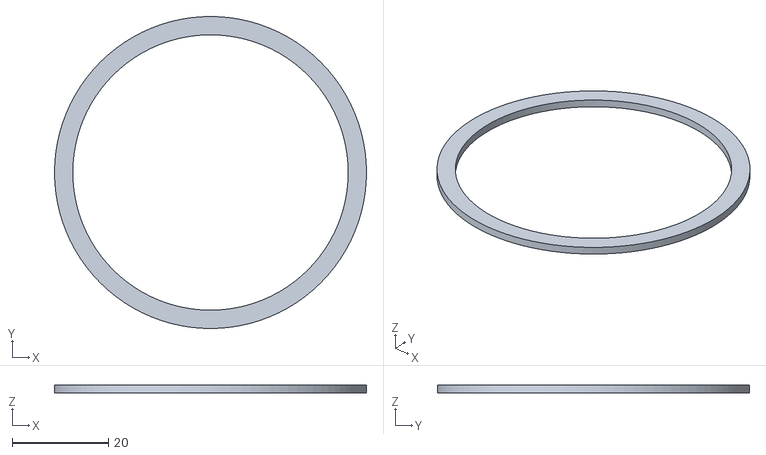
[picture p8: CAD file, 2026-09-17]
build/enclosure_frost.stl
64.8 x 64.8 x 1.60

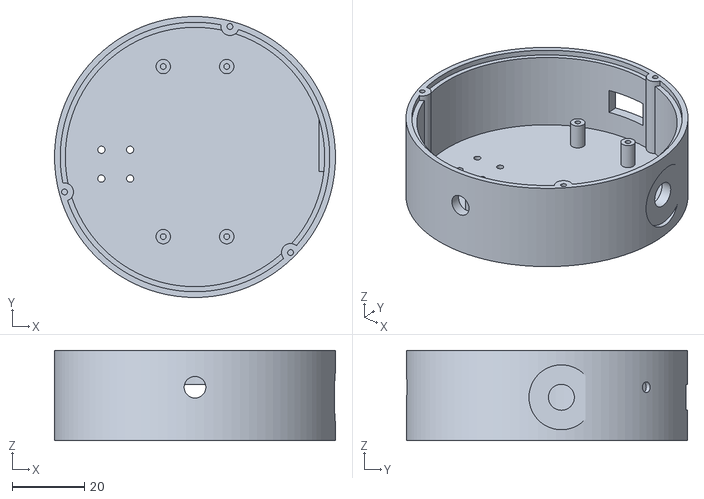
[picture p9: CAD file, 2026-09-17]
build/enclosure_body.stl
78.0 x 78.0 x 25.0

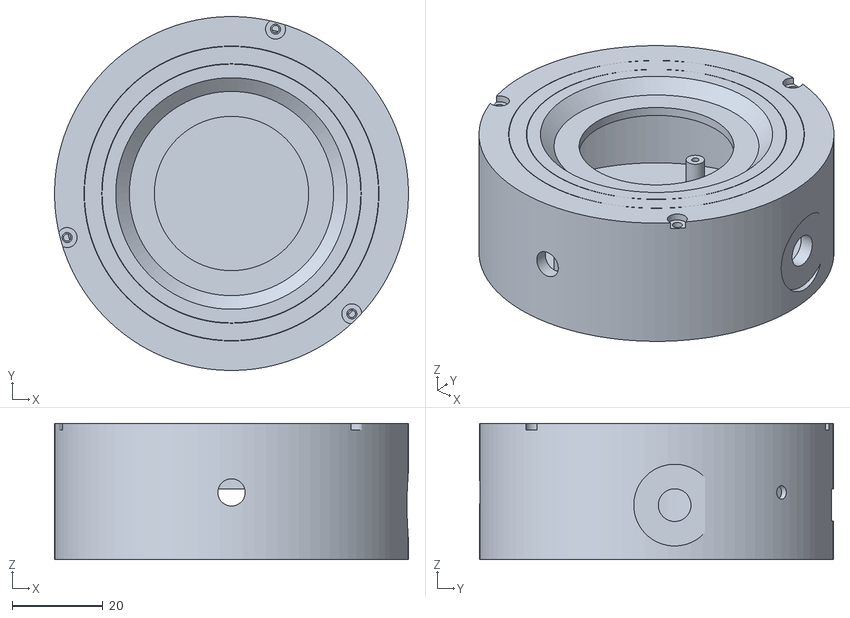
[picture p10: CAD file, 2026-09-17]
build/enclosure.stl
78.0 x 78.0 x 30.0

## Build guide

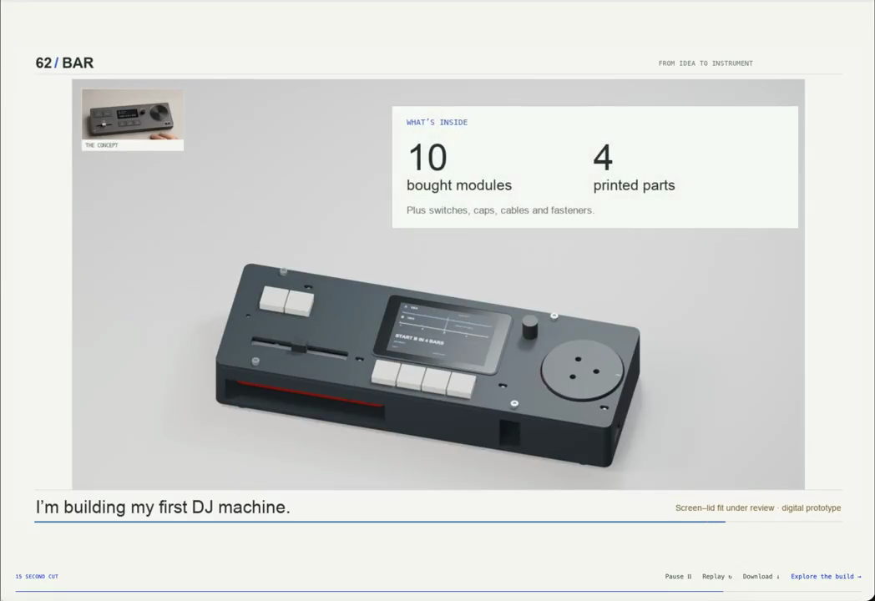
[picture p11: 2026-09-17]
build/ref/f08.png

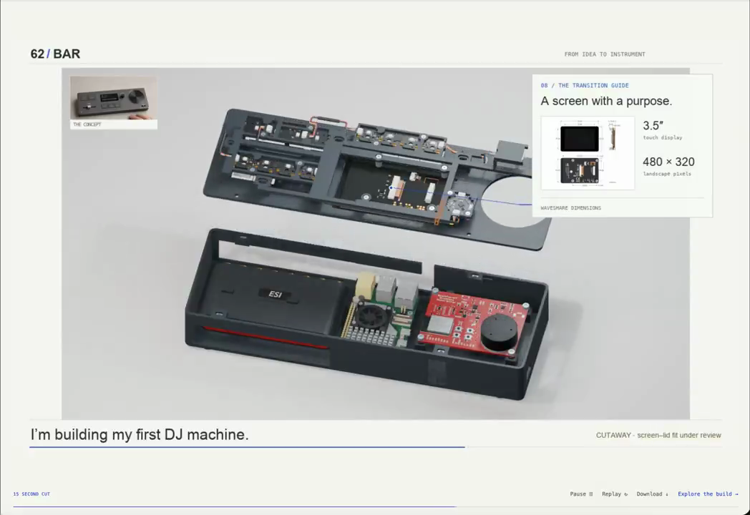
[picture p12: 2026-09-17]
build/ref/f06.png

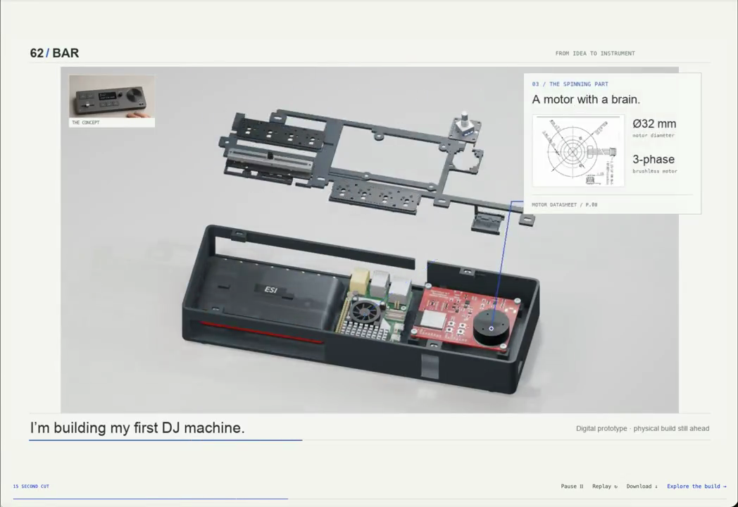
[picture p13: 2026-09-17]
build/ref/f04.png

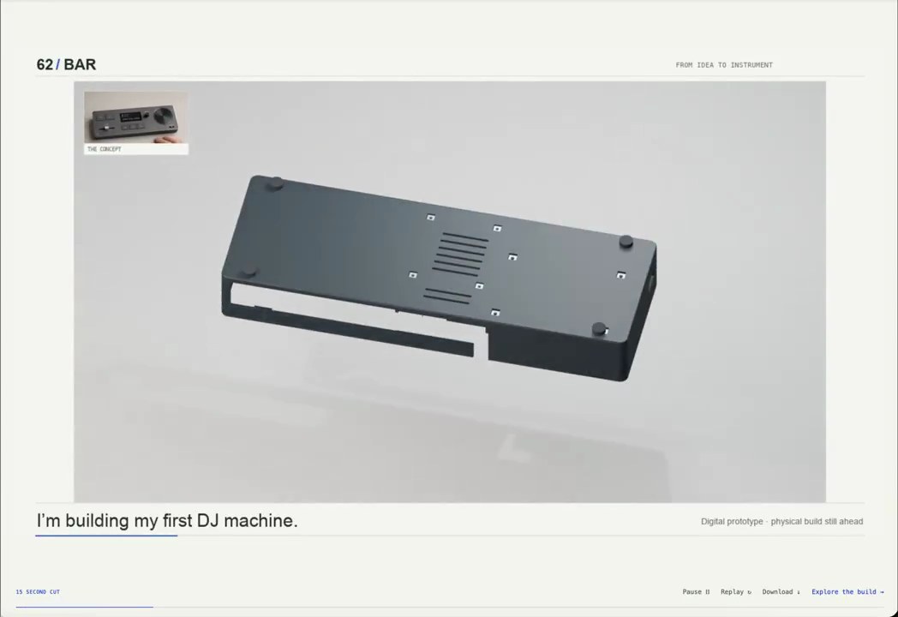
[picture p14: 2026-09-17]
build/ref/f02.png

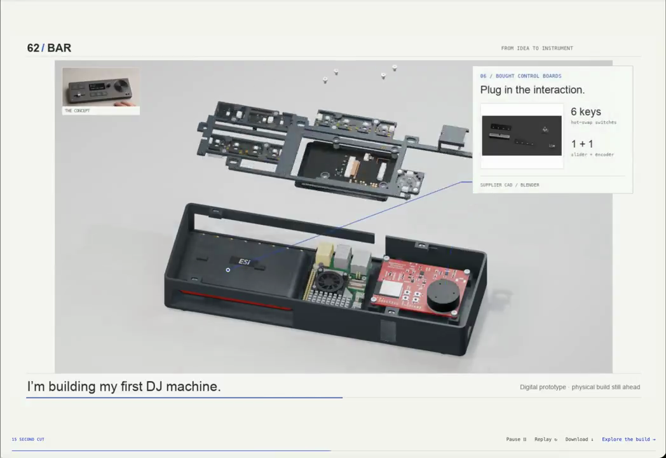
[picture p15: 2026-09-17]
build/ref/f05.png

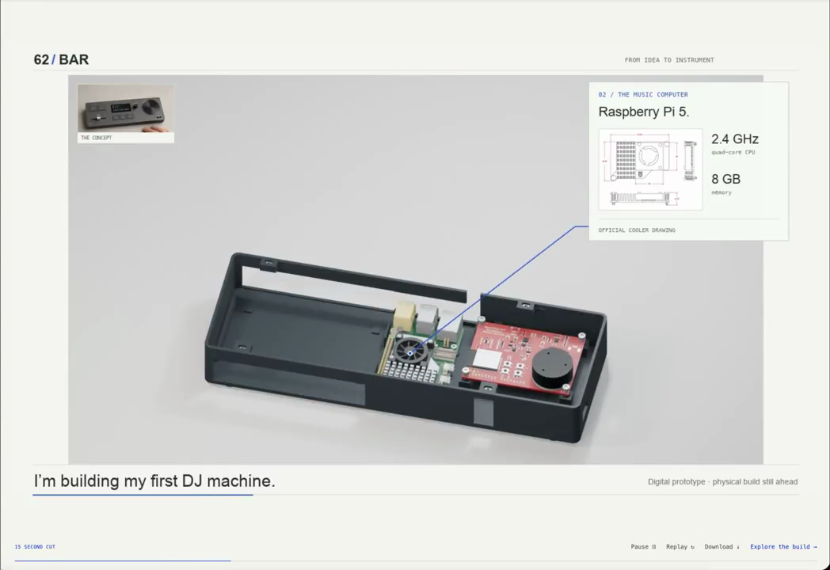
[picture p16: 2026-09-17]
build/ref/f03.png

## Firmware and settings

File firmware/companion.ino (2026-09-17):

// =============================================================================
// Puck — companion.ino
//
// Board: Adafruit Feather ESP32-S3 2MB PSRAM, arduino-esp32 3.3.11.
// Everything tunable lives in config.h. Everything that decides anything lives
// in state_machine.cpp / ui.cpp / leds.cpp, none of which touch hardware — this
// file is the only place that talks to a peripheral.
//
// Library versions (tags fetched from GitHub 2026-09-16, see LIBRARIES.md):
//   Adafruit_GFX 1.12.6 · Adafruit_GC9A01A 1.1.1 · Adafruit_NeoPixel 1.15.5
//   Adafruit_SHT4X 1.0.5 · Adafruit_VEML7700 2.1.6 · Adafruit_STHS34PF80 1.0.2
//   Adafruit_MAX1704X 1.0.3 · Adafruit_BusIO 1.17.4 · arduino-esp32 3.3.11
//
// The Claude usage page's receiver (WiFi + WebServer, both bundled with
// arduino-esp32 3.3.11) is compiled in only when CLAUDE_WIFI_ENABLED is 1.
// =============================================================================
#include <Adafruit_GC9A01A.h>
#include <Adafruit_NeoPixel.h>
#include <Adafruit_SHT4x.h>
#include <Adafruit_STHS34PF80.h>
#include <Adafruit_VEML7700.h>
#include <Arduino.h>
#include <SPI.h>
#include <Wire.h>

#include "config.h"
#include "leds.h"
#include "power.h"
#include "state_machine.h"
#include "ui.h"

#if CLAUDE_WIFI_ENABLED
// Both of these ship with arduino-esp32 3.3.11; nothing is added to the BOM of
// libraries. Verified at tag 3.3.11 by fetching the headers — see LIBRARIES.md.
#include <WebServer.h>
#include <WiFi.h>

#include "secrets.h"  // WIFI_SSID / WIFI_PASS — copy secrets.h.example
#endif

// --- Peripherals -------------------------------------------------------------
// Hardware SPI display. Adafruit_GC9A01A(cs, dc, rst) picks the default SPI
// bus; begin() with no argument uses SPI_DEFAULT_FREQ, which the library sets
// to 40 MHz for ESP32 (verified in Adafruit_GC9A01A.cpp @ 1.1.1).
static Adafruit_GC9A01A tft(PIN_TFT_CS, PIN_TFT_DC, PIN_TFT_RST);
static Adafruit_NeoPixel ring(LED_COUNT, PIN_RING_DIN, NEO_GRB + NEO_KHZ800);
static Adafruit_SHT4x sht4;
static Adafruit_VEML7700 veml;
static Adafruit_STHS34PF80 sths;

// --- State -------------------------------------------------------------------
static SM sm;
static Inputs in;
static Outputs out;
static UiModel model;
static UiModel modelDrawn;   // what is actually on the glass
static bool modelValid = false;

static uint32_t nextTickMs = 0;
static uint32_t lastSensorMs = 0;
static bool presenceLatch = false;   // output of the PRESENCE_ON/OFF hysteresis

// Survives deep sleep: the seconds counter that stands in for a real clock, and
// the flag that says "ext1 fired, treat the first tick as presence".
RTC_DATA_ATTR static uint32_t rtcSeconds = 0;
RTC_DATA_ATTR static bool rtcSeeded = false;

// --- Claude usage, pushed in over HTTP ---------------------------------------
// In RTC memory so a deep-sleep cycle does not throw the numbers away: the
// laptop may well be shut when the puck next wakes. The freshness stamp is the
// same rtcSeconds counter the clock uses, NOT the "ts" field in the payload —
// the device has no real time of day to compare a unix timestamp against, and
// what the page wants to say is "how long since this arrived", which is local.
// That means claudeAgeMin inherits the clock's drift (see CLOCK_TRIM_PPM) and
// under-counts sleep time on an ext1 wake, exactly like the hour ring does.
RTC_DATA_ATTR static float rtcClaudeUsd = 0.0f;
RTC_DATA_ATTR static uint32_t rtcClaudeIn = 0;
RTC_DATA_ATTR static uint32_t rtcClaudeOut = 0;
RTC_DATA_ATTR static int32_t rtcClaudeWindowPct = -1;
RTC_DATA_ATTR static uint32_t rtcClaudeAtSec = 0;  // rtcSeconds when it landed; 0 = never

// --- Encoder -----------------------------------------------------------------
// Full-step quadrature decode in an ISR. The classic 16-entry transition table:
// index = (prev << 2) | now, value = -1 / 0 / +1. Bounces produce table zeros,
// and a short debounce window throws away anything faster than the encoder can
// physically move.
static const int8_t QUAD_TABLE[16] = {0, -1, 1, 0, 1, 0, 0, -1, -1, 0, 0, 1, 0, 1, -1, 0};
static volatile uint8_t encPrev = 0;
static volatile int32_t encAccum = 0;       // quarter-steps
static volatile uint32_t encLastUs = 0;
static volatile bool encSwFlag = false;
static volatile uint32_t encSwLastMs = 0;

static void IRAM_ATTR encIsr() {
  uint32_t nowUs = micros();
  if ((nowUs - encLastUs) < ENC_DEBOUNCE_US) return;
  encLastUs = nowUs;
  uint8_t now = (uint8_t)((digitalRead(PIN_ENC_A) << 1) | digitalRead(PIN_ENC_B));
  encAccum += QUAD_TABLE[(encPrev << 2) | now];
  encPrev = now;
}

static void IRAM_ATTR encSwIsr() {
  uint32_t nowMs = millis();
  if ((nowMs - encSwLastMs) < ENC_SW_DEBOUNCE_MS) return;
  encSwLastMs = nowMs;
  if (digitalRead(PIN_ENC_SW) == LOW) encSwFlag = true;  // active low
}

// Detents, not quarter-steps: the PEC11R gives 4 quadrature edges per detent.
static int encTakeDelta() {
  noInterrupts();
  int32_t acc = encAccum;
  int32_t detents = acc / 4;
  encAccum = acc - detents * 4;
  interrupts();
  return (int)detents;
}

static bool encTakePress() {
  noInterrupts();
  bool p = encSwFlag;
  encSwFlag = false;
  interrupts();
  return p;
}

// --- Clock stand-in ----------------------------------------------------------
// rtcSeconds ticks in RTC memory so the hour survives deep sleep. On a timer
// wake we cannot know how long we were really out beyond T_SLEEP_POLL_S, which
// is exactly what we add.
static uint32_t nowSeconds() {
  return rtcSeconds + (millis() / 1000);
}

static float clockHour() {
  uint32_t secs = nowSeconds();
  double trimmed = (double)secs * (1.0 + (double)CLOCK_TRIM_PPM / 1000000.0);
  double hours = (double)CLOCK_START_HOUR + trimmed / 3600.0;
  while (hours >= 24.0) hours -= 24.0;
  return (float)hours;
}

// --- Claude usage receiver ---------------------------------------------------
// 65535 minutes = "never received", which is what ui_page_claude renders dim.
static uint16_t claudeAgeMin() {
  if (rtcClaudeAtSec == 0) return 65535;
  uint32_t age = nowSeconds() - rtcClaudeAtSec;
  uint32_t mins = age / 60u;
  return (mins > 65534u) ? 65534 : (uint16_t)mins;
}

#if CLAUDE_WIFI_ENABLED
// POWER: off by default, and the demo's power table assumes off. Turning it on
// means a station associated to an AP for as long as the device is awake, not a
// sleeping radio. The ESP32-S3 datasheet gives peaks only — Wi-Fi RX 88 mA —
// and what this code actually costs is the modem-sleep average of an idle
// associated station, which depends on the AP's DTIM and which I have NOT
// measured and did NOT find a datasheet figure for. UNVERIFIED. parts.json
// carries 20 mA as a placeholder for the awake modes, flagged the same way;
// budget against the 88 mA peak until someone puts a meter on it.
static WebServer claudeServer(CLAUDE_HTTP_PORT);
static bool claudeBegun = false;    // WiFi.begin() has been called this boot
static bool claudeServing = false;  // routes installed and listening

// Pull one number out of a flat JSON object. Five scalars, no nesting, no
// arrays, no escapes worth the trouble — strtod beats a 30 kB parser here.
// ponytail: naive key search, a key appearing inside a string value would fool
// it. Swap in ArduinoJson if the payload ever grows objects or strings.
static bool jsonNum(const String& body, const char* key, double* v) {
  String pat = String("\"") + key + "\"";
  int k = body.indexOf(pat);
  if (k < 0) return false;
  int c = body.indexOf(':', k + (int)pat.length());
  if (c < 0) return false;
  const char* p = body.c_str() + c + 1;
  char* end = NULL;
  double d = strtod(p, &end);
  if (end == p) return false;
  *v = d;
  return true;
}

// POST /claude  {"usd":4.2,"in":812000,"out":96000,"window_pct":37,"ts":...}
// "ts" is parsed by nobody: freshness is measured locally (see the RTC block).
static void claudeHandlePost() {
  String body = claudeServer.arg("plain");
  double usd = 0.0, tin = 0.0, tout = 0.0, wpct = -1.0;
  if (!jsonNum(body, "usd", &usd) || !jsonNum(body, "in", &tin) ||
      !jsonNum(body, "out", &tout)) {
    claudeServer.send(400, "text/plain", "want usd/in/out\n");
    return;
  }
  if (!jsonNum(body, "window_pct", &wpct)) wpct = -1.0;
  if (usd < 0.0) usd = 0.0;
  if (tin < 0.0) tin = 0.0;
  if (tout < 0.0) tout = 0.0;
  rtcClaudeUsd = (float)usd;
  rtcClaudeIn = (uint32_t)tin;
  rtcClaudeOut = (uint32_t)tout;
  rtcClaudeWindowPct = (wpct < 0.0) ? -1 : (int32_t)wpct;
  uint32_t at = nowSeconds();
  rtcClaudeAtSec = (at == 0) ? 1 : at;  // 0 is the "never" sentinel
  claudeServer.send(200, "text/plain", "ok\n");
}

// Called once per tick. Never blocks: association takes seconds and the tick
// budget is TICK_MS, so this only ever kicks things off and then polls.
static void claudeService(bool awake) {
  if (!awake) {  // SLEEP: radio down before power_enter_deep_sleep cuts the rest
    if (claudeBegun) {
      claudeServer.stop();
      WiFi.disconnect(true);
      WiFi.mode(WIFI_OFF);
      claudeBegun = false;
      claudeServing = false;
    }
    return;
  }
  if (!claudeBegun) {
    WiFi.mode(WIFI_STA);
    WiFi.setSleep(true);  // modem sleep between beacons; see the power note above
    WiFi.begin(WIFI_SSID, WIFI_PASS);
    claudeBegun = true;
    return;
  }
  if (WiFi.status() != WL_CONNECTED) {
    claudeServing = false;
    return;
  }
  if (!claudeServing) {
    claudeServer.on("/claude", HTTP_POST, claudeHandlePost);
    claudeServer.begin();
    claudeServing = true;
  }
  claudeServer.handleClient();
}
#else
static void claudeService(bool awake) {
  (void)awake;  // Wi-Fi compiled out entirely: no radio, no listener, no cost
}
#endif

// --- Model change detection --------------------------------------------------
// Redraw only when something a human could see has changed: temperature to
// 0.1 degC, humidity and battery to 1 %, the hour tick, page and state.
static bool modelChanged(const UiModel& a, const UiModel& b) {
  if ((int)(a.tempC * 10.0f) != (int)(b.tempC * 10.0f)) return true;
  if ((int)a.rh != (int)b.rh) return true;
  if ((int)a.hour != (int)b.hour) return true;
  if ((int)a.vbatPct != (int)b.vbatPct) return true;
  if (a.charging != b.charging) return true;
  if (a.page != b.page) return true;
  if (a.state != b.state) return true;
  if ((a.lux >= LUX_DAY) != (b.lux >= LUX_DAY)) return true;  // only the threshold matters
  // Claude page: cents, whole-percent window, and the stale/fresh flip only.
  if ((int)(a.claudeUsd * 100.0f) != (int)(b.claudeUsd * 100.0f)) return true;
  if (a.claudeInTok != b.claudeInTok) return true;
  if (a.claudeOutTok != b.claudeOutTok) return true;
  if (a.claudeWindowPct != b.claudeWindowPct) return true;
  if ((a.claudeAgeMin > CLAUDE_STALE_MIN) != (b.claudeAgeMin > CLAUDE_STALE_MIN)) return true;
  return false;
}

// =============================================================================
// setup
// =============================================================================
void setup() {
  // --- Power rails first, before anything can draw current through them ------
  pinMode(PIN_NEOPIXEL_POWER, OUTPUT);
  digitalWrite(PIN_NEOPIXEL_POWER, LOW);  // on-board pixel: never used, stays dark
  pinMode(PIN_RING_POWER, OUTPUT);
  digitalWrite(PIN_RING_POWER, HIGH);     // switched 3.3 V rail up so I2C/ring can init

  // --- Clock: seed on cold boot, advance by the poll interval on a timer wake -
  if (!rtcSeeded) {
    rtcSeconds = 0;
    rtcSeeded = true;
  } else if (esp_sleep_get_wakeup_cause() == ESP_SLEEP_WAKEUP_TIMER) {
    rtcSeconds += T_SLEEP_POLL_S;
  }

  // --- I2C bus: STHS34PF80 0x5A, SHT41 0x44, VEML7700 0x10, MAX17048 0x36 ----
  Wire.begin(PIN_SDA, PIN_SCL);
  Wire.setClock(400000);

  // --- Environment sensor. Medium precision keeps the blocking read short ----
  sht4.begin(&Wire);
  sht4.setPrecision(SHT4X_MED_PRECISION);
  sht4.setHeater(SHT4X_NO_HEATER);

  // --- Light sensor. Fixed gain 1x / 100 ms integration: about 0.06 lx per
  //     count up to ~15 klx, which straddles LUX_NIGHT (5) and LUX_DAY (400)
  //     without the settling delay that auto-ranging costs on every read. -----
  veml.begin(&Wire);
  veml.setGain(VEML7700_GAIN_1);
  veml.setIntegrationTime(VEML7700_IT_100MS);
  veml.enable(true);

  // --- Presence sensor. INT is ACTIVE LOW + open drain so it can share the
  //     ext1 ANY_LOW wake group with the encoder switch (see power.cpp). ------
  sths.begin(I2C_ADDR_PRESENCE, &Wire);
  sths.setBlockDataUpdate(true);
  sths.setObjAveraging(STHS34PF80_AVG_TMOS_128);
  sths.setOutputDataRate(STHS34PF80_ODR_1_HZ);   // 10 uA at 1 Hz
  sths.setIntPolarity(true);                      // true = active low
  sths.setIntOpenDrain(true);
  sths.setIntLatched(false);
  sths.setIntMask(STHS34PF80_PRES_FLAG);          // only presence pulls INT
  sths.setIntSignal(STHS34PF80_INT_OR);

  // --- Fuel gauge (MAX17048 at 0x36) ----------------------------------------
  power_begin();

  // --- Encoder. Both phases and the switch are active low with pull-ups. -----
  pinMode(PIN_ENC_A, INPUT_PULLUP);
  pinMode(PIN_ENC_B, INPUT_PULLUP);
  pinMode(PIN_ENC_SW, INPUT_PULLUP);
  pinMode(PIN_PRESENCE_INT, INPUT_PULLUP);
  encPrev = (uint8_t)((digitalRead(PIN_ENC_A) << 1) | digitalRead(PIN_ENC_B));
  attachInterrupt(digitalPinToInterrupt(PIN_ENC_A), encIsr, CHANGE);
  attachInterrupt(digitalPinToInterrupt(PIN_ENC_B), encIsr, CHANGE);
  attachInterrupt(digitalPinToInterrupt(PIN_ENC_SW), encSwIsr, FALLING);

  // --- Display. SPI pins bound explicitly; MISO unused (display is write-only)
  SPI.begin(PIN_SCK, -1, PIN_MOSI, -1);
  tft.begin();                 // 40 MHz on ESP32 by library default
  tft.setRotation(0);
  tft.fillScreen(COL_BG);
  ledcAttach(PIN_TFT_BL, BL_PWM_FREQ_HZ, BL_PWM_BITS);
  ledcWrite(PIN_TFT_BL, 0);    // stay dark until the state machine says otherwise

  // --- Ring. Rail is already up; keep every pixel dark until leds_compute. ---
  ring.begin();
  ring.setBrightness(255);     // the cap is applied in leds_compute, not here
  ring.clear();
  ring.show();

  // --- State machine --------------------------------------------------------
  sm_init(&sm);

  // --- Wake path: ext1 fired because presence (or the knob) went active, so
  //     force presence true for the first tick. Without this the first
  //     STHS read could land in the gap between frames and we would go
  //     straight back to sleep. ----------------------------------------------
  if (power_woke_from_deep_sleep() &&
      esp_sleep_get_wakeup_cause() == ESP_SLEEP_WAKEUP_EXT1) {
    presenceLatch = true;
  }

  nextTickMs = millis();
}

// =============================================================================
// loop — one pass every TICK_MS
// =============================================================================
void loop() {
  uint32_t now = millis();
  if ((int32_t)(now - nextTickMs) < 0) return;
  nextTickMs += TICK_MS;

  // --- 1. Sensors. SHT41 and VEML7700 at 1 Hz; presence every tick because it
  //        is what decides whether the device is awake at all. ---------------
  static float tempC = 21.0f;
  static float rh = 45.0f;
  static float lux = 100.0f;
  if ((now - lastSensorMs) >= SENSOR_PERIOD_MS) {
    lastSensorMs = now;
    sensors_event_t hum, tmp;
    if (sht4.getEvent(&hum, &tmp)) {
      tempC = tmp.temperature;
      rh = hum.relative_humidity;
    }
    // _NOWAIT: gain and integration time are fixed in setup(), so there is no
    // settling delay to sit through. _CORRECTED applies the high-lux
    // non-linearity fit from the Vishay app note.
    lux = veml.readLux(VEML_LUX_CORRECTED_NOWAIT);
  }

  // --- 2. Presence hysteresis. The raw TPRESENCE count is signed; a warm body
  //        pushes it positive. Two thresholds so a person sitting still at the
  //        edge of the cone does not make the device blink on and off. -------
  int16_t praw = sths.readPresence();
  if (!presenceLatch && praw >= PRESENCE_ON_THRESH) {
    presenceLatch = true;
  } else if (presenceLatch && praw < PRESENCE_OFF_THRESH) {
    presenceLatch = false;
  }

  // --- 3. Assemble the inputs -----------------------------------------------
  in.presence = presenceLatch;
  in.lux = lux;
  in.tempC = tempC;
  in.rh = rh;
  in.hour = clockHour();
  in.encDelta = encTakeDelta();
  in.encPressed = encTakePress();
  in.vbatPct = power_pct();
  in.charging = power_charging();
  in.nowMs = now;

  // --- 4. The only decision point -------------------------------------------
  sm_step(&sm, &in, &out);

  // --- 4b. Claude usage receiver. Awake only: the radio goes down before the
  //         device sleeps, so the default power table is untouched (and with
  //         CLAUDE_WIFI_ENABLED 0 this compiles to nothing at all). ---------
  claudeService(sm.state != SLEEP);

  // --- 5. Backlight. LEDC at BL_PWM_BITS resolution. ------------------------
  uint32_t maxDuty = (1u << BL_PWM_BITS) - 1u;
  uint32_t duty = (uint32_t)(out.backlight * (float)maxDuty + 0.5f);
  if (duty > maxDuty) duty = maxDuty;
  ledcWrite(PIN_TFT_BL, duty);

  // --- 6. Ring. The rail is switched, not just the data: a dark 24-pixel ring
  //        still eats ~24 mA, so RING_OFF means the rail goes down. ----------
  static bool railUp = true;
  if (out.ringOn) {
    if (!railUp) {
      digitalWrite(PIN_RING_POWER, HIGH);
      delay(1);          // let the rail settle before clocking data at it
      ring.begin();      // re-arm the RMT/driver after a power cycle
      railUp = true;
    }
    uint8_t px[LED_COUNT][3];
    leds_compute(out.ringMode, now - out.stateEnteredMs, LED_MAX_BRIGHTNESS, px);
    for (int i = 0; i < LED_COUNT; i++) {
      ring.setPixelColor(i, px[i][0], px[i][1], px[i][2]);
    }
    ring.show();
  } else if (railUp) {
    ring.clear();
    ring.show();
    digitalWrite(PIN_RING_POWER, LOW);
    railUp = false;
  }

  // --- 7. Display. Redraw only when the model actually changed; a full 240x240
  //        repaint at 40 MHz is ~23 ms of SPI we do not want every tick. -----
  if (out.displayOn) {
    model.tempC = tempC;
    model.rh = rh;
    model.hour = in.hour;
    model.vbatPct = in.vbatPct;
    model.charging = in.charging;
    model.page = out.page;
    model.state = sm.state;
    model.lux = lux;
    model.claudeUsd = rtcClaudeUsd;
    model.claudeInTok = rtcClaudeIn;
    model.claudeOutTok = rtcClaudeOut;
    model.claudeWindowPct = (int)rtcClaudeWindowPct;
    model.claudeAgeMin = claudeAgeMin();
    if (!modelValid || modelChanged(model, modelDrawn)) {
      ui_draw(tft, model);
      modelDrawn = model;
      modelValid = true;
    }
  } else {
    modelValid = false;  // next wake always repaints
  }

  // --- 8. Sleep. The state machine has already cut the backlight and the ring
  //        in its outputs; power_enter_deep_sleep does the rest and never
  //        returns. -------------------------------------------------------
  if (sm.state == SLEEP) {
    rtcSeconds += millis() / 1000;
    power_enter_deep_sleep(tft);
  }
}

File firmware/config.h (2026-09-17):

// =============================================================================
// Puck — config.h : every tunable, one per line.
//
// PARSED BY THE BUILD SCRIPT. Each line matching
//     #define ([A-Z0-9_]+) +([-0-9.]+)
// becomes FW.NAME in the browser demo. Keep values plain decimal (no 0x, no
// expressions, no parentheses) or the demo will not see them.
// Change a timing HERE, not in demo/src/*.js.
//
// Library versions this firmware is written against (tags verified on
// GitHub 2026-09-16 by fetching the file at that tag; see firmware/LIBRARIES.md):
//   Adafruit_GFX        1.12.6      Adafruit_GC9A01A   1.1.1
//   Adafruit_NeoPixel   1.15.5      Adafruit_SHT4X     1.0.5
//   Adafruit_VEML7700   2.1.6       Adafruit_STHS34PF80 1.0.2
//   Adafruit_MAX1704X   1.0.3       Adafruit_BusIO     1.17.4
//   arduino-esp32       3.3.11      (board: Adafruit Feather ESP32-S3 2MB PSRAM)
// =============================================================================
#ifndef PUCK_CONFIG_H
#define PUCK_CONFIG_H

// --- Pins (GPIO numbers, from arduino-esp32 3.3.11 -------------------------
// variants/adafruit_feather_esp32s3/pins_arduino.h, read at that tag) --------
#define PIN_SDA 3 // I2C data  — STHS34PF80 0x5A, SHT41 0x44, VEML7700 0x10, MAX17048 0x36
#define PIN_SCL 4 // I2C clock — same bus
#define PIN_RING_POWER 7 // I2C_POWER: switched 3.3 V rail, feeds ONLY the NeoPixel ring
#define PIN_SCK 36 // Display SCK
#define PIN_MOSI 35 // Display MOSI
#define PIN_TFT_CS 10 // Display chip select
#define PIN_TFT_DC 9 // Display data/command
#define PIN_TFT_RST 6 // Display reset
#define PIN_TFT_BL 5 // Display backlight, LEDC PWM
#define PIN_RING_DIN 11 // NeoPixel ring data in
#define PIN_ENC_A 18 // Encoder quadrature A (input pull-up)
#define PIN_ENC_B 17 // Encoder quadrature B (input pull-up)
#define PIN_ENC_SW 16 // Encoder push switch, ACTIVE LOW, pull-up, RTC GPIO (ext1 wake)
#define PIN_PRESENCE_INT 15 // STHS34PF80 INT, configured ACTIVE LOW open-drain, RTC GPIO (ext1 wake)
#define PIN_NEOPIXEL_POWER 21 // On-board single NeoPixel power — held LOW, we never use it

// --- I2C addresses ----------------------------------------------------------
#define I2C_ADDR_PRESENCE 90 // 0x5A STHS34PF80
#define I2C_ADDR_ENV 68 // 0x44 SHT41
#define I2C_ADDR_LUX 16 // 0x10 VEML7700 (fixed, no jumpers)
#define I2C_ADDR_FUEL 54 // 0x36 MAX17048. Older Feather revisions ship an LC709203F at 0x0B — not supported here.

// --- State machine timing (ms unless stated) --------------------------------
#define TICK_MS 100 // main loop period
#define T_WAKE_MS 1500 // WAKE dwell before PRESENT/NIGHT — the ring sweep runs in this window
#define T_AWAY_MS 30000 // AWAY_PENDING grace before deep sleep
#define T_ATTENTION_MS 8000 // idle after the last knob input before leaving ATTENTION
#define T_SLEEP_POLL_S 60 // deep-sleep timer wake, seconds (fuel gauge + lux housekeeping)
#define RING_LOWBATT_MS 2000 // low-battery warning window measured from entering WAKE

// --- Light thresholds (lux) -------------------------------------------------
#define LUX_NIGHT 5 // below this the room counts as night
#define LUX_HYST 3 // must climb above LUX_NIGHT+LUX_HYST to leave night
#define LUX_DAY 400 // above this the room is daylight-bright: UI uses full-contrast ticks

// --- Backlight duty (0..1) --------------------------------------------------
#define BL_PRESENT 0.40 // someone is there, quiet display
#define BL_NIGHT 0.10 // dark room, do not blind anybody
#define BL_ATTENTION 1.0 // hand on the knob, or waking up
#define BL_PWM_FREQ_HZ 20000 // LEDC frequency, above audible
#define BL_PWM_BITS 10 // LEDC resolution (0..1023)

// --- NeoPixel ring ----------------------------------------------------------
#define LED_COUNT 24 // NeoPixel Ring 24 (ADA1586), GRB
#define LED_MAX_BRIGHTNESS 0.20 // hard cap on every channel; ring draws ~312 mA at this cap
#define LED_SWEEP_MS 1200 // one full comet lap during WAKE
#define LED_SWEEP_FADE_MS 300 // comet fade-out after the lap (1200+300 = T_WAKE_MS)
#define LED_TAIL 6 // comet tail length in pixels
#define LED_BREATH_MS 2600 // ATTENTION breathing period
#define LED_BREATH_FLOOR 0.25 // ATTENTION dims to this fraction, never fully off
#define LED_PULSE_MS 400 // one low-battery pulse (on+off)
#define LED_PULSE_COUNT 3 // number of low-battery pulses, then dark
#define LED_WARM_R 255 // WAKE comet colour, warm white
#define LED_WARM_G 170 // WAKE comet colour
#define LED_WARM_B 90 // WAKE comet colour
#define LED_AMBER_R 255 // ATTENTION breathing colour
#define LED_AMBER_G 150 // ATTENTION breathing colour
#define LED_AMBER_B 40 // ATTENTION breathing colour
#define LED_RED_R 255 // LOW_BATT pulse colour
#define LED_RED_G 30 // LOW_BATT pulse colour
#define LED_RED_B 20 // LOW_BATT pulse colour
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
